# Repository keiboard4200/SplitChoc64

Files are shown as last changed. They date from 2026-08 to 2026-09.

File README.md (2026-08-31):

# SplitChoc64

SplitChoc64 is a 64-key split low-profile keyboard project built around Seeed XIAO nRF52840 and ZMK.

This repository contains firmware/software, PCB design, mechanical/3D-print data, manufacturing outputs, and project documentation.

## Repository layout

```text
SplitChoc64/
├─ hardware/                 # PCB, case, plate, trackball mechanical data and manufacturing files
│  ├─ main-pcb/
│  │  ├─ Ver000/
│  │  └─ Ver001/
│  └─ trackball-addon/
├─ software/                 # ZMK build/config/module source and archived firmware variants
│  ├─ build.yaml
│  ├─ west.yml
│  ├─ zmk-module/            # active Ver001 ZMK module
│  ├─ firmware/
│  │  ├─ joystick/           # legacy Ver000/2765 implementation
│  │  └─ trackball/          # Ver001 PAW3222 documentation
│  └─ tools/
├─ docs/                     # Project documentation
├─ archive/                  # Historical/original import data
├─ DEVELOPMENT/              # Development snapshots retained for traceability
├─ zephyr/module.yml         # Zephyr entry point redirecting to software/zmk-module
├─ .github/                  # GitHub Actions
└─ README.md
```

## Hardware baseline

- **Ver000**: first manufactured SplitChoc64 production hardware baseline (legacy internal name: Ver012).
- **Ver001**: current manufactured hardware/firmware baseline, stored under `hardware/main-pcb/Ver001/`.
- Kailh Choc V2 hot-swap switches.
- Seeed XIAO nRF52840 Plus on both halves.

## Active Ver001 pointing device

Ver001 uses the RIGHT-side PAW3222 trackball through the PCB-mounted 6-pin FFC interface. The active ZMK module under `software/zmk-module/` is configured for this hardware.

The older 2765 analog-joystick implementation is retained only as a legacy reference under `software/firmware/joystick/`; it is not compiled into the active Ver001 firmware.

Detailed Ver001 trackball wiring and firmware notes are in `software/firmware/trackball/README.md`.

## ZMK build

GitHub Actions reads:

- Build matrix: `software/build.yaml`
- West/config path: `software/`
- SplitChoc64 Zephyr/ZMK module: `software/zmk-module/`

`zephyr/module.yml` remains at repository root because ZMK/Zephyr module discovery expects the module entry point there. The implementation is organized under `software/`.

## Firmware identity

- Shield: `splitchoc64_left` / `splitchoc64_right`
- RIGHT: Central / USB-BLE host / PAW3222 trackball
- LEFT: Peripheral
- Bluetooth name: `SplitChoc64`
- ZMK Studio: retained
- `settings_reset` build: retained

## Validation status

GitHub Actions validates LEFT, RIGHT, and `settings_reset` builds. Physical PAW3222 direction, CPI and feel must still be tuned on the assembled Ver001 hardware.

## License

See the license files and upstream component licenses included with each subproject before redistribution or commercial use.

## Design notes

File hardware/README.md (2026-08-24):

# Hardware

This directory contains PCB source data, manufacturing outputs, and hardware-specific documentation.

## Main PCB

`main-pcb/Ver012/` is the frozen production baseline for the manufactured SplitChoc64 PCB.

Do not change:
- PCB outline
- key positions
- left/right interlocking geometry

## Trackball add-on

`trackball-addon/` contains the J4-to-FFC adapter PCB and associated manufacturing/mechanical data for the PAW3222/Torabo variant.

Where practical, keep editable source data and manufacturing outputs together and clearly versioned.

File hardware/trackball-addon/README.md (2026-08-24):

# Trackball add-on hardware

This directory is the canonical location for the SplitChoc64 trackball add-on.

## Version baseline

- Formal repository production version: **Ver000**
- Legacy/internal package label: **Ver003**
- Ver000 preserves the approved Ver003 payload unchanged; only repository-level version designation is changed.
- Next trackball add-on revision: **Ver001**

## Mechanical baseline

- Torabo-tsuki LP 19 mm holder geometry
- 19.05 mm POM ball
- PAW3222 14 mm mouse sensor module
- dedicated R27 trackball adapter
- trackball-enabled RIGHT bottom case

## FFC adapter

The adapter PCB connects RIGHT J4 to a 6-pin 0.5 mm FFC connector.

### J4 mapping

| J4 | Function |
|---|---|
| 1 | 3V3 |
| 2 | GND |
| 3 | SCLK / P0.02 |
| 4 | SDIO / P0.03 |
| 5 | MOTION / P0.28 |
| 6 | CS / P0.04 |
| 7 | SPARE / P0.05 |

### FFC-side mapping

| J2 | Function |
|---|---|
| 1 | GND |
| 2 | SCLK |
| 3 | SDIO |
| 4 | MOTION |
| 5 | CS |
| 6 | 3V3 |

The physical connector orientation and same-side FFC contact direction must be checked during assembly; do not infer conductor order from the U-fold alone.

## Manufacturing baseline

The approved adapter mechanical revision is R27. Reference assemblies are for fit/visualization only and are not themselves manufacturing parts.

Legacy filenames and internal documents may still contain `Ver003`, `R27`, or `R26`; those names are intentionally retained for traceability to the approved manufacturing data.

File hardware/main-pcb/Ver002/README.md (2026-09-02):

# SplitChoc64 Ver002

Clean GitHub source promoted from the user-reviewed XIAO nRF52840 Plus correction.

- `0_COMMON`: shared footprints / 3D assets
- `1_RIGHT`: RIGHT KiCad project + ERC/DRC reports
- `2_LEFT`: LEFT KiCad project + ERC/DRC reports
- `3_PLATE`: accepted TopPlate STEP files
- `4_CASE`: accepted BottomCase / BatteryLid / trackball mechanical STEP files
- Manufacturing exports are intentionally not carried forward from Ver001; regenerate them from Ver002 when needed.

Validation confirmed by the user in KiCad 9.0 before promotion: LEFT/RIGHT ERC 0/0 and DRC 0/0.

Ver002 corrects XIAO nRF52840 Plus pads 28/29, removes unverified pads 30/31, preserves the project-specific front-side solder access pads 32/33, and leaves Ver001 unchanged as historical source.

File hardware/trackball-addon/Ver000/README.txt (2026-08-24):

SplitChoc64 Trackball Add-on Ver003

Purpose:
  Manufacturing package for the SplitChoc64 Ver012 trackball add-on.
  The original Ver012 keyboard PCB geometry is not modified by this package.

Folder layout:
  1_FFC_ADAPTER/   KiCad 9 data for the J4 1.27 mm -> 6P 0.5 mm FFC adapter
  2_3D_PRINT/      3D manufacturing data separated by printable part
    1_TORABO_TRACKBALL_HOLDER/  Torabo-tsuki 19 mm trackball holder
    2_ADAPTER/                  SplitChoc64 external trackball adapter
    3_BOTTOM_CASE/              RIGHT bottom case with trackball interface / FFC pass-through
    4_REFERENCE_ASSEMBLY/       Reference-only assembled placement model; do not manufacture as one part
  3_DOCUMENTS/     Pin map, FFC routing and assembly notes
  VALIDATION_STAGE/ hashes and packaging notes

Important:
  The three manufacturing STEP files under folders 1-3 are each a single valid solid.
  The reference assembly is for placement/fit visualization only.

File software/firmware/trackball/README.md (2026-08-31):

# SplitChoc64 Ver001 trackball firmware

Ver001 uses the PAW3222-based 14 mm mouse-sensor module on the RIGHT / Central half through the PCB-mounted 6-pin FFC connector.

## Ver001 hardware interface

The finalized RIGHT PCB exposes the trackball through J6 (`FH19C-6S-0.5SH`) on the B-side.

PCB J6 net order:

| J6 pin | PCB net | XIAO pin | nRF52840 GPIO |
|---|---|---|---|
| 1 | GND | GND | - |
| 2 | R_EXT_A | D0/A0 | P0.02 |
| 3 | R_EXT_B | D1/A1 | P0.03 |
| 4 | R_EXT_SDA | D4/SDA | P0.04 |
| 5 | R_EXT_SCL | D5/SCL | P0.05 |
| 6 | 3V3 | 3V3 | - |

The sensor-module FFC order is `1=3V3, 2=CS, 3=MOTION, 4=SDIO, 5=SCLK, 6=GND`.
With the same-electrode FFC between the opposing connectors, the order is reversed at the PCB connector. Therefore the firmware assignment is:

| PAW3222 signal | XIAO / GPIO |
|---|---|
| SCLK | D0 / P0.02 |
| SDIO | D1 / P0.03 |
| MOTION | D4 / P0.04 |
| CS | D5 / P0.05 |

The PAW3222 uses 3-wire SPI, so the same SDIO GPIO is assigned to both SPIM MOSI and MISO.

## ZMK integration

The active Ver001 build uses `sekigon-gonnoc/zmk-driver-paw3222` as a West module. RIGHT remains the split Central / USB-BLE host-facing half, and the trackball is local to RIGHT, so split input relay is not required for the normal Ver001 configuration.

The Ver000/legacy 2765 joystick implementation is retained separately under `software/firmware/joystick/` and is not compiled into the active Ver001 build.

## Initial Ver001 behavior

- Trackball: normal pointer movement through PAW3222
- Lay1: explicit mouse buttons and scroll key controls retained
- Lay3: Bluetooth/output management and ZMK Studio unlock retained
- Legacy joystick tuning bindings removed from the active Ver001 keymap

Pointer CPI/rotation and ball-based scrolling should be tuned on the assembled Ver001 hardware after physical bring-up.

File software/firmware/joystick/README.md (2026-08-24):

# Joystick firmware

This directory is a snapshot of the validated SplitChoc64 ZMK firmware for the RIGHT-side 2765 analog joystick configuration.

## Status

- RIGHT = Central / USB-BLE host
- LEFT = Peripheral
- Current production PCB baseline = Ver012
- JOY_X = P0.02 / ADC0
- JOY_Y = P0.03 / ADC1
- Sampling target = 125 Hz
- ZMK Studio retained

During the repository-layout migration, the same firmware is intentionally kept at repository root so the existing GitHub Actions workflow is not broken before path-aware build validation is completed.

Do not modify Ver012 hardware geometry from firmware work.

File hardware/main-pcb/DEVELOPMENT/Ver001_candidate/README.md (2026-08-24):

# SplitChoc64 Ver001 candidate — DEVELOPMENT

**Status: under development / not a formal release.**

This directory is intentionally separated from formal `Ver000` and future formal `Ver001`.
It contains the current DRC-clean PCB candidate while mechanical and connector changes are still pending.

Current PCB baseline:
- LEFT: final mating outline, H4 moved 3.0 mm left, user routing corrections, local silk fix.
- RIGHT: final mating outline, user routing corrections, local silk fix.
- DRC: user-confirmed 0 errors / 0 warnings on 2026-08-24 using the Ver000 project rule set.
- Component placement, nets and schematic intent otherwise inherit Ver000 unless explicitly changed above.
- KiCad project/schematic/library tables and referenced component 3D models are inherited from Ver000.

Mating geometry:
- Main seam key-center pitch accepted at approximately 20.05 mm.
- Case inner wall target: PCB edge +0.2 mm clearance.
- Case wall thickness target: 1.0 mm.

## Next development tasks
1. Change J3/J4 to FFC connectors.
2. Change the battery connector so the battery-side terminal does not need modification.
3. Design the top plate as 3D-printable data.
4. Define/design the bottom plate.

Do not generate manufacturing data from this folder until these tasks are complete and DRC/mechanical checks are repeated.

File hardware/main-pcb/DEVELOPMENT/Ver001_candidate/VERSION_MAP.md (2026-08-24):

# Production Version Map

| Repository version | Legacy/internal label | Meaning |
|---|---|---|
| Ver000 | Ver012 | First manufactured SplitChoc64 production hardware baseline |
| Ver001 | — | Reserved for the first future hardware revision |

The Ver000 design payload is intentionally preserved from the source package originally named `splitchoc64_Ver012.zip`. Legacy names inside KiCad files, validation documents, STEP filenames, and manufacturing outputs are retained for traceability rather than rewritten.

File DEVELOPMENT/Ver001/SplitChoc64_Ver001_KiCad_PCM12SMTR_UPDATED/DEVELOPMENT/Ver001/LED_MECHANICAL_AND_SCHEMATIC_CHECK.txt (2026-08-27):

SplitChoc64 Ver001 LED verification

Mechanical placement
- LED package target: ROHM SMLD12WBN1W1 class, 1.6 x 0.8 x ~0.55 mm.
- LED centers remain at each switch-local (0, -5.15 mm), transformed by switch rotation.
- This position is within the intended Kailh Choc LED-window region used for the V1/V2 hybrid layout.
- No dedicated PCB opening is added.

Silkscreen
- Added visible F.SilkS user text: LED
- Removed the old cathode line at local x=-0.95 mm because it crossed pad 1.
- New cathode line: local x=-1.45 mm, y=-0.45..+0.45 mm, width 0.12 mm.
- Pad 1 local copper/mask x extent: -1.15..-0.35 mm.
- Centerline clearance from pad/mask edge: 0.30 mm; closest silk line edge clearance: ~0.24 mm.

Schematic cross-check
- Repository schematic is older than the uploaded Ver001 PCB state.
- Repository LEFT schematic still contains J3 as 7-pin and old JOY signal naming.
- Uploaded PCB U1 already uses L_EXT_A, L_EXT_B, L_BL_PWM, L_EXT_SDA, L_EXT_SCL etc.
- Therefore an LED-only schematic edit would preserve an existing PCB/schematic mismatch.
- Schematic was intentionally NOT overwritten in this package; a current synchronized schematic source is required before making the full schematic update safely.

No LED routing was added.

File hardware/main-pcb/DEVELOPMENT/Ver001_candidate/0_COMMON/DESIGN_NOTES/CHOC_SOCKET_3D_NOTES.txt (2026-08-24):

SplitChoc64 STAGE279 - Kailh Choc hot-swap socket 3D

Part: CPG135001S30
Applied to: 64 switch footprints
Model: kailh_choc_socket_CPG135001S30_MECH.step

Case-design focus:
- Socket is on the PCB underside.
- Nominal modeled underside depth: 1.85 mm.
- Do not design the case floor exactly tangent to the model.
- Recommended next step is to inspect the assembled PCB in KiCad 3D Viewer and
  then establish the real battery + socket + solder clearance stack.

This is a mechanical clearance model, not an official Kailh STEP.

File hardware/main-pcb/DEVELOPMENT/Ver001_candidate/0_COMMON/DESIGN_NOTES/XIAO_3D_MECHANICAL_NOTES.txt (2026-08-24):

SplitChoc64 STAGE278 - XIAO nRF52840 Plus 3D mechanical model

Purpose:
- Enclosure / case clearance review.
- USB-C connector overhang verification.

Dimensions taken from the existing U1/U2 footprint:
- XIAO module PCB body: approximately 20.950 x 17.800 mm
- USB-C envelope: 6.350 x 7.620 mm
- USB-C protrusion beyond XIAO PCB edge: 1.515 mm

Important:
This STEP is a mechanical proxy. The PCB body and USB-C envelope follow the
existing footprint geometry. Small components are representative shapes.
It is not claimed to be an official Seeed Studio XIAO nRF52840 Plus STEP model.

For case design, the USB-C opening should not be made exactly 1.515 mm deep;
provide assembly/printing tolerance around the connector.

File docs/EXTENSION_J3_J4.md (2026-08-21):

# J3/J4 expansion header (Ver012)

The five signal pins are deliberately **not consumed by RC1**.

| Header pin | Net suffix | XIAO pad | XIAO name | nRF52840 |
|---|---|---:|---|---|
| 1 | 3V3 | 12 | 3V3 | power |
| 2 | GND | 13/33 | GND | ground |
| 3 | JOY_X | 1 | D0 | P0.02 |
| 4 | JOY_Y | 2 | D1 | P0.03 |
| 5 | JOY_SW | 3 | D2 | P0.28 |
| 6 | JOY_SDA | 5 | D4 | P0.04 |
| 7 | JOY_SCL | 6 | D5 | P0.05 |

This leaves all five GPIO signals available for a future analog joystick, I2C device,
or remapped SPI pointing-device interface without changing the manufactured keyboard PCB.

Do not add the pointing driver to RC1 until the base keyboard firmware has been validated.

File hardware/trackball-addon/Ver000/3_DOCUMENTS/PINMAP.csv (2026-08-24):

J4/J1 pin | J4 net | Adapter J2 pin | FFC conductor to sensor pin | Sensor signal
1 | 3V3 | 6 | 1 | 3V3
2 | GND | 1 | 6 | GND
3 | SCLK | 2 | 5 | SCLK
4 | SDIO | 3 | 4 | SDIO
5 | MOTION | 4 | 3 | MOTION
6 | CS | 5 | 2 | CS
7 | SPARE | NC | NC | NC

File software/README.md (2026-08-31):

# Software

This directory contains the software and firmware side of SplitChoc64.

## Layout

- `build.yaml` — ZMK build matrix used by GitHub Actions.
- `west.yml` — West manifest for fetching ZMK and dependencies.
- `zmk-module/` — SplitChoc64 Zephyr/ZMK module source, board/shield definitions, devicetree bindings and C sources.
- `firmware/joystick/` — preserved joystick firmware variant.
- `firmware/trackball/` — trackball firmware variant.
- `tools/` — software-side helper and validation tools.

## Build integration

The repository keeps only `zephyr/module.yml` at the repository root as the Zephyr module entry point. It points into `software/zmk-module/`.

GitHub Actions uses `software/build.yaml` as the build matrix and `software/` as the ZMK config path. This keeps the repository root readable without changing the hardware tree.

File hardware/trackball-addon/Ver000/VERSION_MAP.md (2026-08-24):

# Trackball Add-on Version Map

| Repository version | Legacy/internal label | Meaning |
|---|---|---|
| Ver000 | Ver003 | First approved/manufactured SplitChoc64 trackball add-on baseline |
| Ver001 | — | Reserved for the first future trackball add-on revision |

The Ver000 payload is intentionally preserved from the data previously managed as Trackball Add-on Ver003. Internal R27/R26 and Ver003 names are retained where present for traceability rather than rewritten.

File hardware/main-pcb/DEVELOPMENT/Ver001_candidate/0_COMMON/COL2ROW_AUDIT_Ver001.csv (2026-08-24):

Side | key | switch | diode | ROW | SW_to_K | A_to_COL
LEFT | 1 | SWL1 | DL1 | L_ROW0 | L_K1_D | L_COL0
LEFT | 2 | SWL2 | DL2 | L_ROW0 | L_K2_D | L_COL1
LEFT | 3 | SWL3 | DL3 | L_ROW0 | L_K3_D | L_COL2
LEFT | 4 | SWL4 | DL4 | L_ROW0 | L_K4_D | L_COL3
LEFT | 5 | SWL5 | DL5 | L_ROW0 | L_K5_D | L_COL4
LEFT | 6 | SWL6 | DL6 | L_ROW0 | L_K6_D | L_COL5
LEFT | 7 | SWL7 | DL7 | L_ROW1 | L_K7_D | L_COL0
LEFT | 8 | SWL8 | DL8 | L_ROW1 | L_K8_D | L_COL1
LEFT | 9 | SWL9 | DL9 | L_ROW1 | L_K9_D | L_COL2
LEFT | 10 | SWL10 | DL10 | L_ROW1 | L_K10_D | L_COL3
LEFT | 11 | SWL11 | DL11 | L_ROW1 | L_K11_D | L_COL4
LEFT | 12 | SWL12 | DL12 | L_ROW1 | L_K12_D | L_COL5
LEFT | 13 | SWL13 | DL13 | L_ROW2 | L_K13_D | L_COL0
LEFT | 14 | SWL14 | DL14 | L_ROW2 | L_K14_D | L_COL1
LEFT | 15 | SWL15 | DL15 | L_ROW2 | L_K15_D | L_COL2
LEFT | 16 | SWL16 | DL16 | L_ROW2 | L_K16_D | L_COL3
LEFT | 17 | SWL17 | DL17 | L_ROW2 | L_K17_D | L_COL4
LEFT | 18 | SWL18 | DL18 | L_ROW2 | L_K18_D | L_COL5
LEFT | 19 | SWL19 | DL19 | L_ROW3 | L_K19_D | L_COL0
LEFT | 20 | SWL20 | DL20 | L_ROW3 | L_K20_D | L_COL1
LEFT | 21 | SWL21 | DL21 | L_ROW3 | L_K21_D | L_COL2
LEFT | 22 | SWL22 | DL22 | L_ROW3 | L_K22_D | L_COL3
LEFT | 23 | SWL23 | DL23 | L_ROW3 | L_K23_D | L_COL4
LEFT | 24 | SWL24 | DL24 | L_ROW3 | L_K24_D | L_COL5
LEFT | 25 | SWL25 | DL25 | L_ROW4 | L_K25_D | L_COL0
LEFT | 26 | SWL26 | DL26 | L_ROW4 | L_K26_D | L_COL1
LEFT | 27 | SWL27 | DL27 | L_ROW4 | L_K27_D | L_COL2
LEFT | 28 | SWL28 | DL28 | L_ROW4 | L_K28_D | L_COL3
LEFT | 29 | SWL29 | DL29 | L_ROW4 | L_K29_D | L_COL4
RIGHT | 1 | SWR1 | DR1 | R_ROW0 | R_K1_D | R_COL0
RIGHT | 2 | SWR2 | DR2 | R_ROW0 | R_K2_D | R_COL1
RIGHT | 3 | SWR3 | DR3 | R_ROW0 | R_K3_D | R_COL2
RIGHT | 4 | SWR4 | DR4 | R_ROW0 | R_K4_D | R_COL3
RIGHT | 5 | SWR5 | DR5 | R_ROW0 | R_K5_D | R_COL4
RIGHT | 6 | SWR6 | DR6 | R_ROW0 | R_K6_D | R_COL5
RIGHT | 7 | SWR7 | DR7 | R_ROW0 | R_K7_D | R_COL6
RIGHT | 8 | SWR8 | DR8 | R_ROW0 | R_K8_D | R_COL7
RIGHT | 9 | SWR9 | DR9 | R_ROW1 | R_K9_D | R_COL0
RIGHT | 10 | SWR10 | DR10 | R_ROW1 | R_K10_D | R_COL1
RIGHT | 11 | SWR11 | DR11 | R_ROW1 | R_K11_D | R_COL2
RIGHT | 12 | SWR12 | DR12 | R_ROW1 | R_K12_D | R_COL3
RIGHT | 13 | SWR13 | DR13 | R_ROW1 | R_K13_D | R_COL4
RIGHT | 14 | SWR14 | DR14 | R_ROW1 | R_K14_D | R_COL5
RIGHT | 15 | SWR15 | DR15 | R_ROW1 | R_K15_D | R_COL6
RIGHT | 16 | SWR16 | DR16 | R_ROW1 | R_K16_D | R_COL7
RIGHT | 17 | SWR17 | DR17 | R_ROW2 | R_K17_D | R_COL0
RIGHT | 18 | SWR18 | DR18 | R_ROW2 | R_K18_D | R_COL1
RIGHT | 19 | SWR19 | DR19 | R_ROW2 | R_K19_D | R_COL2
RIGHT | 20 | SWR20 | DR20 | R_ROW2 | R_K20_D | R_COL3
RIGHT | 21 | SWR21 | DR21 | R_ROW2 | R_K21_D | R_COL4
RIGHT | 22 | SWR22 | DR22 | R_ROW2 | R_K22_D | R_COL5
RIGHT | 23 | SWR23 | DR23 | R_ROW2 | R_K23_D | R_COL6
RIGHT | 24 | SWR24 | DR24 | R_ROW3 | R_K24_D | R_COL0
RIGHT | 25 | SWR25 | DR25 | R_ROW3 | R_K25_D | R_COL1
RIGHT | 26 | SWR26 | DR26 | R_ROW3 | R_K26_D | R_COL2
RIGHT | 27 | SWR27 | DR27 | R_ROW3 | R_K27_D | R_COL3
RIGHT | 28 | SWR28 | DR28 | R_ROW3 | R_K28_D | R_COL4
RIGHT | 29 | SWR29 | DR29 | R_ROW3 | R_K29_D | R_COL5
RIGHT | 30 | SWR30 | DR30 | R_ROW4 | R_K30_D | R_COL0
RIGHT | 31 | SWR31 | DR31 | R_ROW4 | R_K31_D | R_COL1
RIGHT | 32 | SWR32 | DR32 | R_ROW4 | R_K32_D | R_COL2
RIGHT | 33 | SWR33 | DR33 | R_ROW4 | R_K33_D | R_COL3
RIGHT | 34 | SWR34 | DR34 | R_ROW4 | R_K34_D | R_COL4
RIGHT | 35 | SWR35 | DR35 | R_ROW4 | R_K35_D | R_COL5

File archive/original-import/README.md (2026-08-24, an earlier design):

# Original import archive

This directory preserves the original user-uploaded manufacturing source archive before repository relabeling.

- Original filename: `splitchoc64_Ver012.zip`
- Legacy/internal hardware label: `Ver012`
- Formal repository production version: **Ver000**

The archive is retained unchanged for traceability. The canonical extracted production data is under `hardware/main-pcb/Ver000/`.

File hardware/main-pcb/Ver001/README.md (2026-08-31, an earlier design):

# SplitChoc64 Ver001

Clean GitHub upload package, organized to follow Ver000.

- `0_COMMON`: shared footprints / 3D assets
- `1_RIGHT`: RIGHT KiCad project + latest ERC/DRC reports
- `2_LEFT`: LEFT KiCad project + latest ERC/DRC reports
- `3_PLATE`: accepted TopPlate STEP files
- `4_CASE`: accepted BottomCase / BatteryLid / trackball mechanical STEP files
- `5_MANIFUCTUR`: manufacturing exports (LEFT/RIGHT fabrication ZIPs and expanded Gerber/drill outputs)

Validation reports included with KiCad projects:
- LEFT: ERC 0 errors / 0 warnings; DRC 0 violations / 0 unconnected / 0 footprint errors
- RIGHT: ERC 0 errors / 0 warnings; DRC 0 violations / 0 unconnected / 0 footprint errors

`SHA256SUMS.txt` records SHA-256 values that were explicitly verified for the release-critical PCB and mechanical source artifacts. It is not a claim that the files under `5_MANIFUCTUR` were regenerated from the current KiCad PCB in this repository. A byte-for-byte regenerated Gerber/drill comparison requires a matching KiCad 9 `kicad-cli` environment.

The current accepted mechanical revisions in `4_CASE` include Ver001.006 LEFT BottomCase, Ver001.005 RIGHT BottomCase, Ver001.006 LEFT/RIGHT BatteryLids, Ver001.004 LEFT/RIGHT TopPlates, and the LEFT/RIGHT trackball adapters. The trackball-holder STEP is retained as a manufacturing/mechanical dependency but is not listed in `SHA256SUMS.txt` unless its SHA-256 has been explicitly revalidated.

This package intentionally omits intermediate revision files, temporary validation notes, screenshots, old mechanical versions, and development history artifacts.

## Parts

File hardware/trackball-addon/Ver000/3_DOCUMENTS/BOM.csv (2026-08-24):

Ref | Item | Specification | Qty | Notes
J1 | Low-profile pin header/socket | 1x7 1.27mm pitch | 1 | Mates with SplitChoc64 Ver012 J4
J2 | FFC/FPC connector | Hirose FH19C-6S-0.5SH(10) or footprint-compatible | 1 | 6P 0.5mm; B-side mount
FFC | Flat flexible cable | 6P 0.5mm same-contact-side | 1 | U-fold 180 degrees; no twist
SENSOR | Mouse sensor module | 14mm PAW3222 module | 1 | Purchased module; not fabricated in this package
BALL | Trackball | 19.05mm nominal | 1 | Torabo-tsuki LP 19mm configuration

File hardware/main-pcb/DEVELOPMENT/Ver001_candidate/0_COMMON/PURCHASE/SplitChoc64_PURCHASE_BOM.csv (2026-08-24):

Category | Part | MPN | Left | Right | Total | Recommended purchase qty | Recommended source | Notes
MCU | Seeed Studio XIAO nRF52840 Plus | 102010672 | 1 | 1 | 2 | 3 | Seeed Studio Japan | Exact Plus version required; one spare recommended.
Keyboard diode | 1N4148WS SOD-323 | JSCJ 1N4148WS / LCSC C2128 | 29 | 35 | 64 | 70 | LCSC | SOD-323. Pin 1 = cathode (K). Align the diode body cathode band with the PCB K/bar mark.
Status LED | Blue LED 0603 | KT-0603B / C2288 | 1 | 1 | 2 | 50 | LCSC | LCSC minimum 50; polarity critical.
LED resistor | 100Ω 1% 0603 | 0603WAF1000T5E / C22775 | 1 | 1 | 2 | 100 | LCSC | Any equivalent 100Ω 0603 1% is acceptable.
Power switch | SPDT slide switch | C&K PCM12SMTR | 1 | 1 | 2 | 4 | DigiKey | Obsolete; buy spares. Exact mechanical footprint matters.
Battery PCB connector | JST SH 2-pin SMT | BM02B-SRSS-TB(LF)(SN) / C160388 | 1 | 1 | 2 | 5 | LCSC | 1.0mm pitch; fine hand-soldering.
Joystick header | 1.27mm 1x7 male header | generic | 1 | 1 | 2 | 4 | DigiKey/Mouser/Akizuki | Confirm pin diameter fits 0.70mm drill.
Joystick | 2-axis analog joystick | JT8P-3.2T-B10K-1-16Y | 1 | 1 | 2 | 3 | Akizuki | Requires wiring/adapter to J3/J4.
Hotswap socket | Kailh Choc hotswap socket | CPG135001S30 | 29 | 35 | 64 | 70 | Yusha Kobo | 10-pack product; buy 7 packs.
Key switch | Kailh Choc V2 | e.g. CPG135301D01 Red | 29 | 35 | 64 | 70 | Yusha Kobo / Marutsu Eleshop | Two 35-packs gives 70.
Battery mating lead | JST SH 2-pin housing/contact | SHR-02V-S(-B) + SSH-003T-P0.2-H | 1 | 1 | 2 | 3 | DigiKey/Mouser | Pre-crimped lead recommended.
Battery | LiPo ~502535 3.7V ~400mAh | DTP502535 or equivalent | 1 | 1 | 2 | 2 | Reputable battery seller | Check polarity, protection circuit and actual thickness.

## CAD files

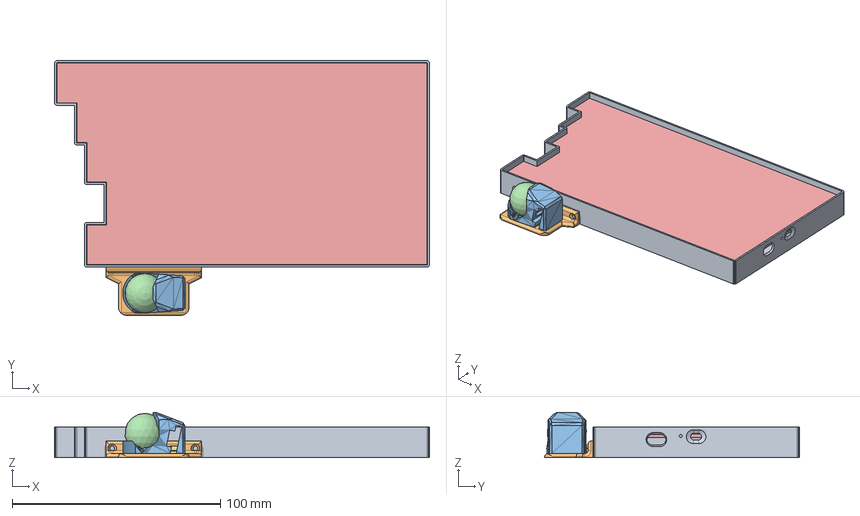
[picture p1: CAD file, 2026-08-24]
hardware/trackball-addon/Ver000/2_3D_PRINT/SplitChoc64_Trackball_Reference_Assembly_R26.step
180.1 x 122.3 x 21.8 mm
RIGHT_BOTTOM_CASE_R24
FINAL_ADAPTER_R24
TORABO19_CASE
BALL_19_005
RIGHT_PCB_REFERENCE
J4_TO_FFC_ADAPTER_PCB_11x8x0.8
J4_1x7_1.27_MATING_CONNECTOR_ENVELOPE
FFC_6P_0.5_CONNECTOR_OPENING_AWAY_FROM_HOLE
FFC_OUTWARD_SEGMENT
FFC_180_FOLDBACK_REGION
FFC_RETURN_SEGMENT
FFC_INTO_EXISTING_SIDEWALL_HOLE

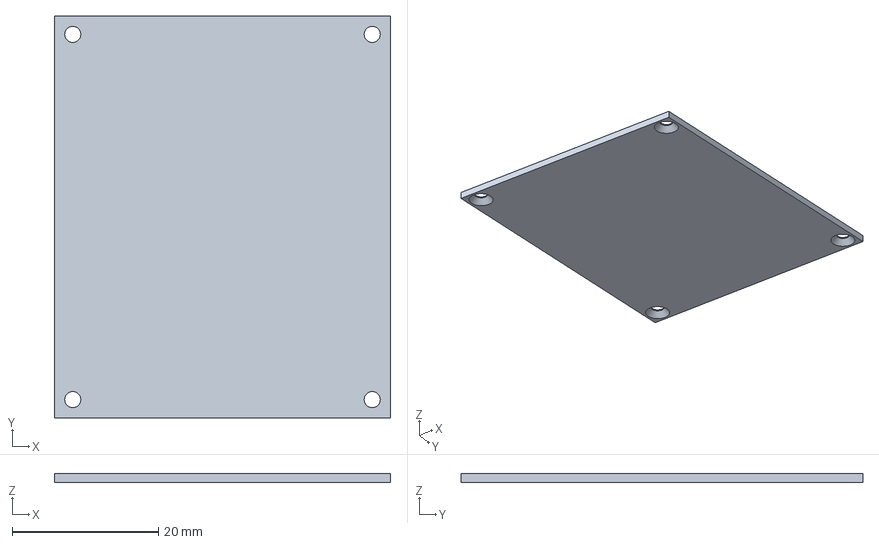
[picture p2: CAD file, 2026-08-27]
DEVELOPMENT/Ver001/SplitChoc64_Ver001_KiCad_PCM12SMTR_UPDATED/DEVELOPMENT/Ver001/MECHANICAL/BottomCase_V1/SplitChoc64_LEFT_BatteryLid_V1.step
46.0 x 55.0 x 1.20 mm

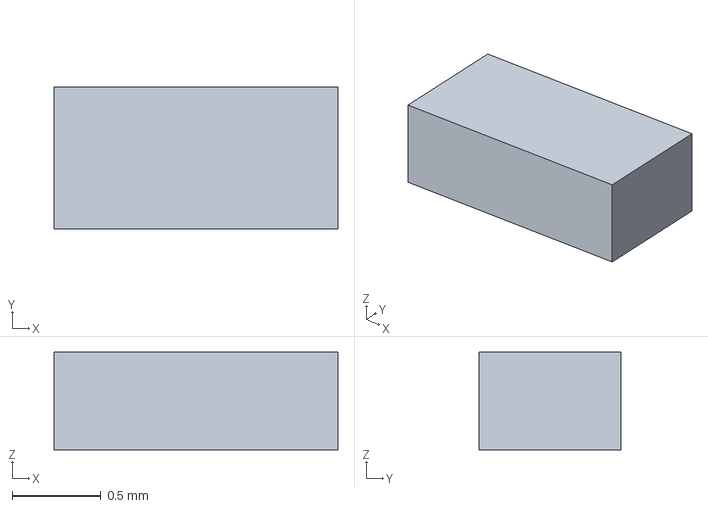
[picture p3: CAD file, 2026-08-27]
hardware/main-pcb/Ver002/1_RIGHT/3dmodels/LED_0603_1608_TOP_PROXY.step
1.60 x 0.8 x 0.55 mm

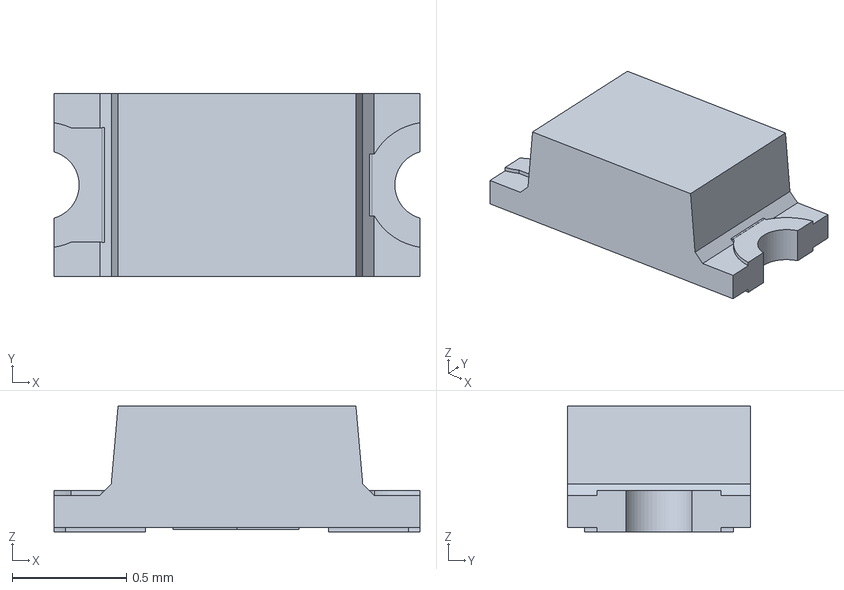
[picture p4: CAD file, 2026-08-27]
hardware/main-pcb/Ver002/2_LEFT/3dmodels/ROHM_SMLD12WBN1W1_KICAD_ALIGNED.step
1.60 x 0.8 x 0.55 mm

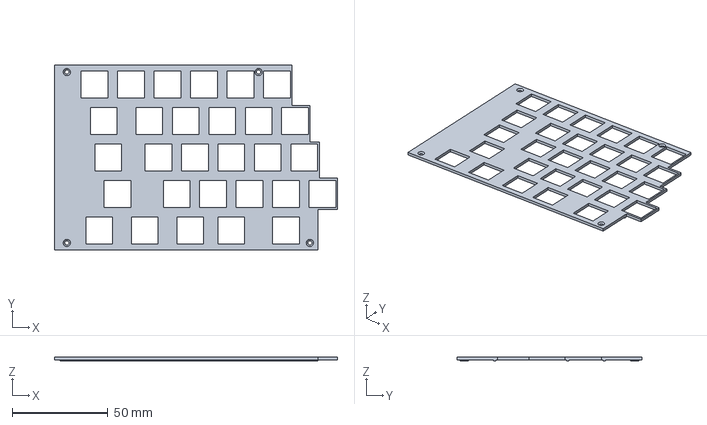
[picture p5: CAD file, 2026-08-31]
hardware/main-pcb/Ver002/3_PLATE/SplitChoc64_LEFT_TopPlate.step
147.9 x 96.8 x 2.10 mm

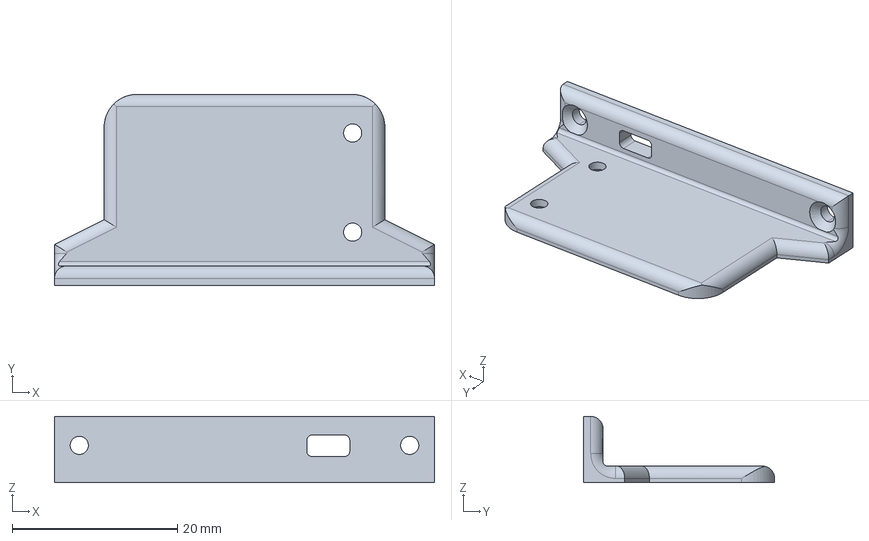
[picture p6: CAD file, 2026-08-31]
hardware/main-pcb/Ver002/4_CASE/SplitChoc64_LEFT_Trackball_Adapter.step
46.0 x 23.2 x 8.00 mm

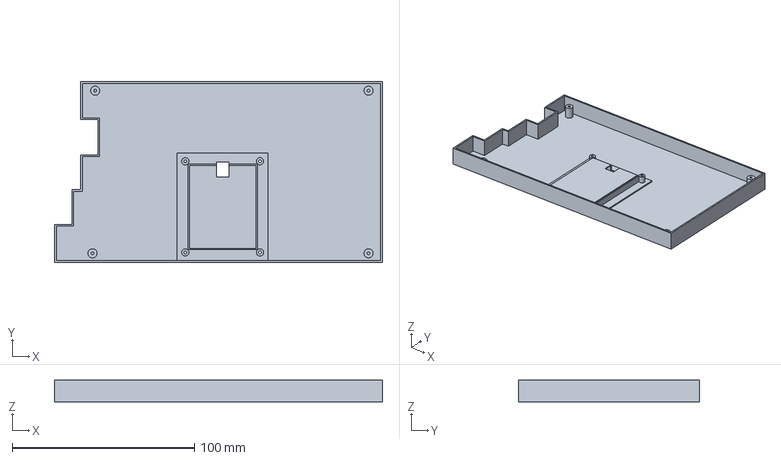
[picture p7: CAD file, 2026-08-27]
DEVELOPMENT/Ver001/SplitChoc64_Ver001_KiCad_PCM12SMTR_UPDATED/DEVELOPMENT/Ver001/MECHANICAL/BottomCase_V1/SplitChoc64_RIGHT_BottomCase_V1.step
180.0 x 99.2 x 11.9 mm

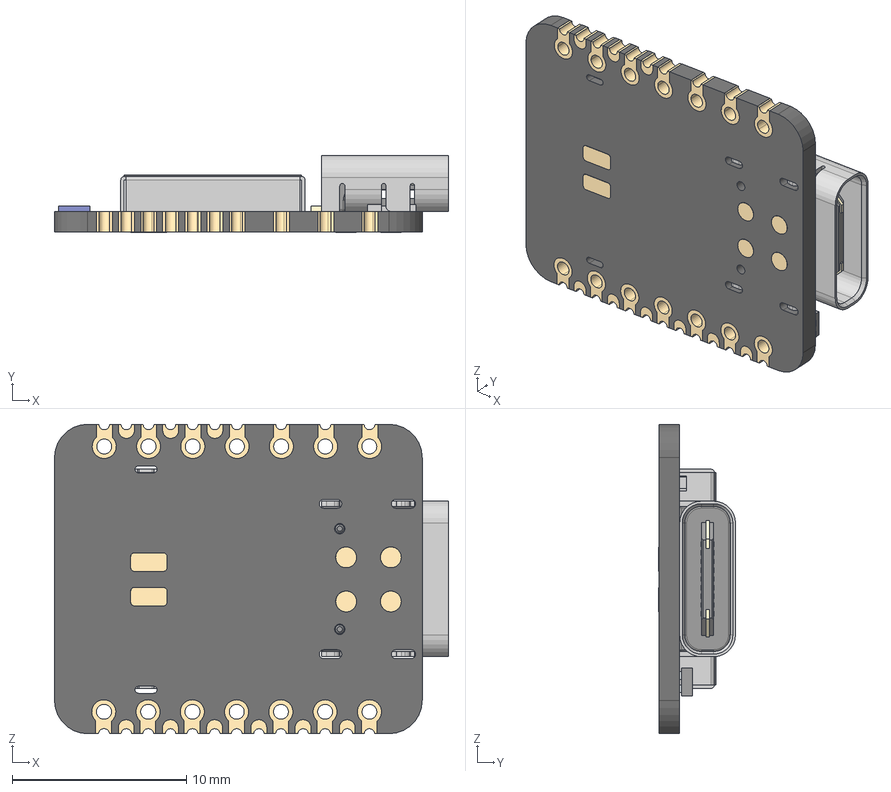
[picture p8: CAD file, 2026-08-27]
hardware/main-pcb/Ver002/1_RIGHT/3dmodels/xiao-nrf52840-plus-v2.step
22.6 x 4.42 x 17.8 mm
BOSS-EXTRUDE14_8_
BOSS-EXTRUDE7_4_
BOSS-EXTRUDE7_3_
BOSS-EXTRUDE14_4_
BOSS-EXTRUDE14_2_
BOSS-EXTRUDE14_11_
BOSS-EXTRUDE7_7_
BOSS-EXTRUDE14_9_
BOSS-EXTRUDE14_3_
BOSS-EXTRUDE14_7_
MIRROR2
BOSS-EXTRUDE14_5_
BOSS-EXTRUDE14_12_
BOSS-EXTRUDE7_8_
BOSS-EXTRUDE7_1_
BOSS-EXTRUDE14_10_
BOSS-EXTRUDE7_9_
BOSS-EXTRUDE14_6_
BOSS-EXTRUDE14_1_
BOSS-EXTRUDE7_6_
BOSS-EXTRUDE7_2_
CUT-EXTRUDE5
BOSS-EXTRUDE7_5_
Shield
Pins

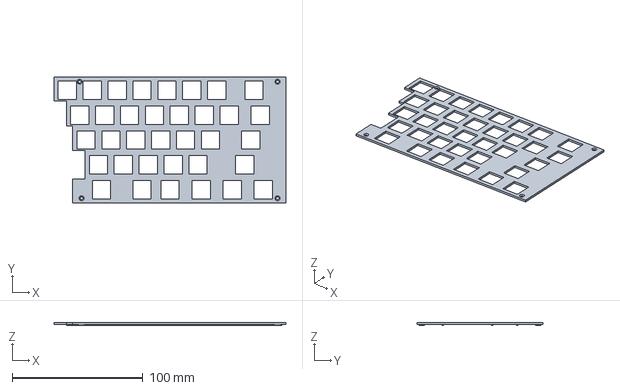
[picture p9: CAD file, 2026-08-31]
hardware/main-pcb/Ver002/3_PLATE/SplitChoc64_RIGHT_TopPlate.step
177.6 x 96.8 x 2.10 mm

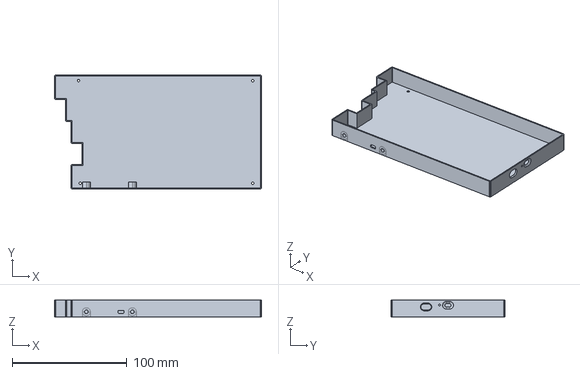
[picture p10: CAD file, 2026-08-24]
hardware/trackball-addon/Ver000/2_3D_PRINT/SplitChoc64_RIGHT_BottomCase_Trackball.step
180.1 x 99.2 x 14.7 mm

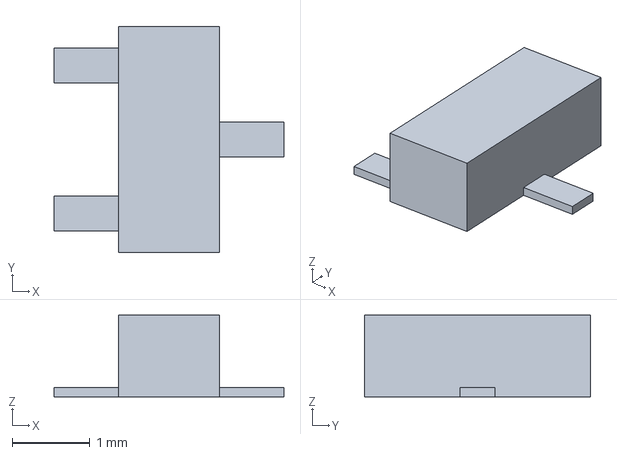
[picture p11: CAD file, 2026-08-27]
hardware/main-pcb/Ver002/1_RIGHT/3dmodels/2N7002_SOT23_KICAD_ALIGNED.step
2.95 x 2.90 x 1.05 mm

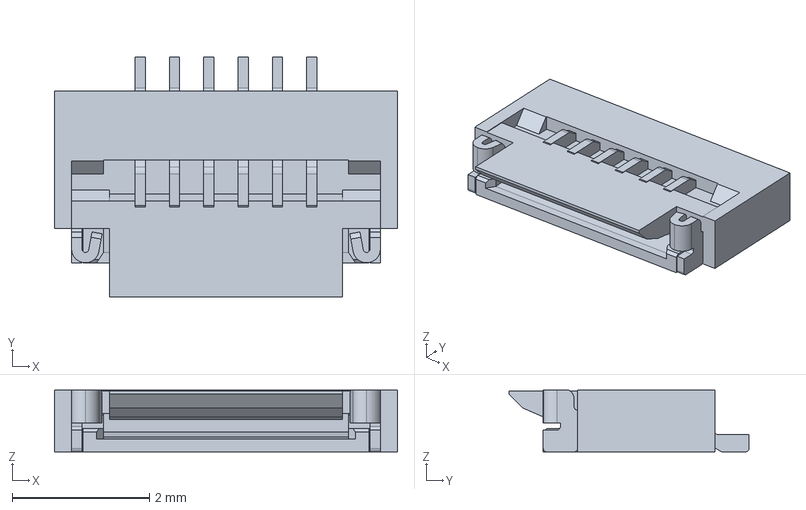
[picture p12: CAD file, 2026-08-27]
hardware/main-pcb/Ver002/2_LEFT/3dmodels/Hirose_FH19C-6S-0.5SH10_KICAD_ALIGNED.step
5.00 x 3.50 x 0.9 mm

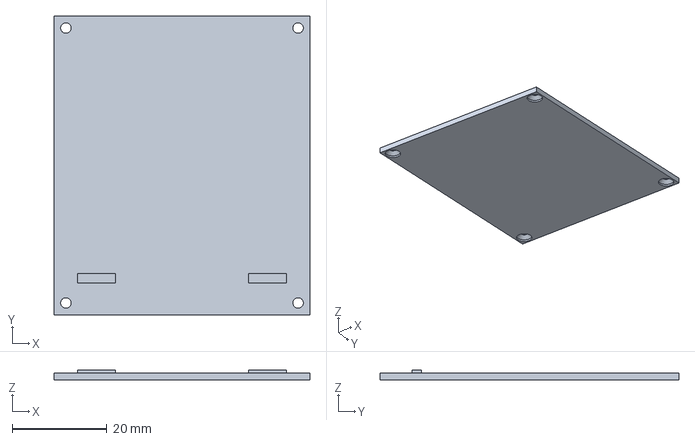
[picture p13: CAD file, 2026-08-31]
hardware/main-pcb/Ver002/4_CASE/SplitChoc64_VER001.006_RIGHT_BatteryLid.step
54.0 x 63.0 x 2.10 mm

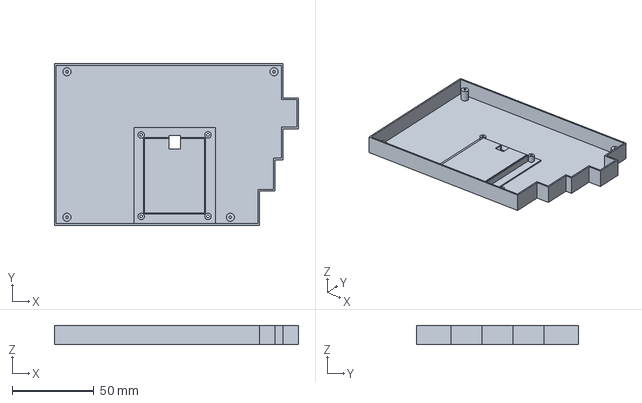
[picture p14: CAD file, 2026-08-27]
DEVELOPMENT/Ver001/SplitChoc64_Ver001_KiCad_PCM12SMTR_UPDATED/DEVELOPMENT/Ver001/MECHANICAL/BottomCase_V1/SplitChoc64_LEFT_BottomCase_V1.step
149.7 x 99.2 x 11.9 mm

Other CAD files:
hardware/main-pcb/Ver002/2_LEFT/3dmodels/LED_0603_1608_TOP_PROXY.step
DEVELOPMENT/Ver001/SplitChoc64_Ver001_KiCad_PCM12SMTR_UPDATED/DEVELOPMENT/Ver001/MECHANICAL/BottomCase_V1/SplitChoc64_RIGHT_BatteryLid_V1.step
hardware/main-pcb/Ver002/1_RIGHT/3dmodels/JST_S2B-PH-SM4-TB_KICAD_ALIGNED.step
DEVELOPMENT/Ver001/SplitChoc64_Ver001_KiCad_PCM12SMTR_UPDATED/DEVELOPMENT/Ver001/MECHANICAL/BottomCase_V1/SplitChoc64_LEFT_BatteryLid_V1.stl
DEVELOPMENT/Ver001/SplitChoc64_Ver001_KiCad_PCM12SMTR_UPDATED/DEVELOPMENT/Ver001/MECHANICAL/BottomCase_V1/SplitChoc64_LEFT_BottomCase_V1.stl
DEVELOPMENT/Ver001/SplitChoc64_Ver001_KiCad_PCM12SMTR_UPDATED/DEVELOPMENT/Ver001/MECHANICAL/BottomCase_V1/SplitChoc64_RIGHT_BatteryLid_V1.stl
DEVELOPMENT/Ver001/SplitChoc64_Ver001_KiCad_PCM12SMTR_UPDATED/DEVELOPMENT/Ver001/MECHANICAL/BottomCase_V1/SplitChoc64_RIGHT_BottomCase_V1.stl
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

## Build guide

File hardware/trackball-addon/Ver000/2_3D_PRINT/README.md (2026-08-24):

# Trackball Add-on Ver003 — 3D assets

The manufacturing package contains these STEP assets:

| Role | File | SHA-256 |
|---|---|---|
| Torabo-tsuki 19 mm holder | `1_TORABO_TRACKBALL_HOLDER/ToraboTsuki_Trackball_Holder_19mm.step` | `7717395efcfe289285835eb16c14c3fb0391c115903c83dc3d8a7b22ab0351f0` |
| SplitChoc64 trackball adapter | `2_ADAPTER/SplitChoc64_Trackball_Adapter.step` | `a29724234e68b600f6e96f09fd6a59213defe4a1de254774ebe799ba476616b3` |
| RIGHT bottom case | `3_BOTTOM_CASE/SplitChoc64_RIGHT_BottomCase_Trackball.step` | `a944e31e2f75782416efe2137fbc5e2f5e7dd0b45cc209864cb6c01c5debe6c8` |
| Reference assembly only | `4_REFERENCE_ASSEMBLY/SplitChoc64_Trackball_Reference_Assembly_R26.step` | `32b3b926071d22d73088b5ba36c1fba255c9a211daec2f892ff4ab1aff8d536f` |

The first three files are manufacturing components. The R26 assembly is reference-only and must not be manufactured as one part.

The source package is `SplitChoc64_Trackball_Addon_Ver003.zip`. The STEP binaries are intentionally tracked separately from the text/KiCad import in this migration step because the connected GitHub writer used for this migration only accepts text or inline blob content and is not suitable for multi-megabyte CAD binaries. The hashes above are authoritative for later binary upload verification.

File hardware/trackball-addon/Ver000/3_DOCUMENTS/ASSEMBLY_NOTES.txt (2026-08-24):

SplitChoc64 Trackball Add-on assembly notes

Signal path:
SplitChoc64 RIGHT J4 -> J1 on adapter PCB -> J2 (B-side) -> 6P 0.5 mm FFC -> PAW3222 14 mm sensor module.

Adapter J2 pin map:
1 GND
2 SCLK
3 SDIO
4 MOTION
5 CS
6 3V3

Sensor module connector pin map:
1 3V3
2 CS
3 MOTION
4 SDIO
5 SCLK
6 GND

With the intended connector facing arrangement and same-contact-side FFC, the physical conductor mapping is adapter 1..6 -> sensor 6..1.
The FFC is U-folded for routing; it is not twisted.

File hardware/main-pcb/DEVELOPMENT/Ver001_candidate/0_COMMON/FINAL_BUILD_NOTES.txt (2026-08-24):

SplitChoc64 Ver000 FINAL

ASSEMBLY
- JLCPCB is used for bare-PCB fabrication only.
- PCBA quantity: 0 components.
- All electronic components are hand-soldered.
- No JLCPCB PCBA BOM/CPL is included.
- Purchase list: 0_COMMON/PURCHASE/SplitChoc64_PURCHASE_BOM.csv

3D
- U1/U2 and all SWL/SWR footprints are now classified as SMD and are no longer excluded from position files.
- XIAO / Choc socket / Choc switch STEP files are copied into each side's local 3dmodels folder.
- This is intended to make them visible in the whole-board KiCad 3D Viewer without relying on P/V special filters.
- No copper, pad, routing, footprint coordinate or Edge.Cuts geometry was changed.

HAND-SOLDERING RISKS
1. JST SH BM02B-SRSS-TB: 1.0mm-pitch SMD; use flux, magnification and a fine tip/hot air.
2. 0603 LED/resistor: small; LED polarity must be checked.
3. 64x 1N4148W: cathode orientation must be checked before soldering.
4. XIAO Plus BAT_SW/GND bottom pads: use the designed plated access slots; solder method needs care.
5. PCM12SMTR: orientation-sensitive and obsolete; buy spare units because the footprint is exact.
6. Choc hot-swap sockets: plastic can deform from excessive iron dwell time.
7. Battery/JST polarity: verify with a multimeter before connecting a LiPo.
8. Joystick is not a direct PCB footprint here; J3/J4 are 1.27mm 1x7 headers, so wiring/adapter is needed.

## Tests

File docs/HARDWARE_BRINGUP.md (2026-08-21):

# Hardware bring-up sequence

1. Flash `settings_reset` once to both XIAO modules if they have existing ZMK bonds/settings.
2. Flash `splitchoc64_left` to LEFT and connect LEFT by USB.
3. Verify LEFT's 29 switches.
4. Flash `splitchoc64_right` to RIGHT.
5. Verify BLE split and all 64 switches.
6. Verify USB and BLE host operation.
7. Only after the base keyboard is proven, add J3/J4 pointing-device firmware.

Do not troubleshoot the future pointing-device driver at the same time as the first matrix/split bring-up.

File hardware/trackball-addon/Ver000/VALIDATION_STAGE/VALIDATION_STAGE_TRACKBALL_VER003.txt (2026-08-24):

SplitChoc64 Trackball Add-on Ver003 validation

3D manufacturing data separated into three standalone STEP files:
- Torabo-tsuki 19 mm holder: 1 solid, valid
- SplitChoc64 trackball adapter: 1 solid, valid
- SplitChoc64 RIGHT bottom case: 1 solid, valid

Adapter source: final R27 (M2 countersunk mounting holes).
Bottom-case source: final R27 case, including the accepted sidewall FFC pass-through.
Torabo holder source: user-provided Fusion-converted Torabo 19 mm STEP.
R26 is retained only as a reference assembly.

Historical DRC reports are intentionally not included.

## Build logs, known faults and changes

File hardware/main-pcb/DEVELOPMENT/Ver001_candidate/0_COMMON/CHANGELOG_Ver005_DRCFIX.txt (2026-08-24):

SplitChoc64 Ver005 — DRC-fix reissue

Reviewed supplied Ver004 DRC reports:
RIGHT: 71 violations; {'silk_over_copper': 36, 'silk_overlap': 35}; unconnected=0; footprint errors=0
LEFT:  59 violations; {'silk_over_copper': 30, 'silk_overlap': 29}; unconnected=0; footprint errors=0

Corrections:
- Kept the user-requested Ver005 logo positions:
  LEFT  (60, 89) mm
  RIGHT (280, 89) mm
- Kept the Choc socket as a filled B.SilkS top-view projection, but removed fill over
  the switch footprint's B.Mask / exposed pad and hole regions with 0.25 mm clearance.
  This addresses the socket silk_over_copper warnings instead of merely suppressing them.
- Moved each keyboard diode 'K' text from local x=-2.55 to x=-3.20 so it no longer
  overlaps its own cathode bar, addressing the silk_overlap warnings.
- No copper, pad, track, net, component coordinate, mounting-hole or Edge.Cuts changes.
- Schematics unchanged.

A fresh KiCad DRC must be run by the user on this reissued Ver005 to verify zero warnings.

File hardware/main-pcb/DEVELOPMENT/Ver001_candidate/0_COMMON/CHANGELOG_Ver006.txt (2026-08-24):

SplitChoc64 Ver006

- LEFT logo moved 5 mm left and 3 mm down: (60,89) -> (55,92).
- Added project-local 3D models to DLED1/DLED2 and RLED1/RLED2.
- Added project-local BM02B-SRSS-TB mechanical proxy to J1/J2.
- DLED/RLED/J1/J2 are explicitly SMD so board-wide 3D Viewer visibility is less filter-dependent.

Ver005 DRC handling:
- RIGHT: 4 silk_edge_clearance warnings at DR1/DR9/DR17/DR24 K labels.
  These K labels were moved inward.
- LEFT: 1 silk_over_copper warning at the SplitChoc64 logo.
  The requested logo move changes that location.
- Both reports: 0 unconnected pads, 0 footprint errors.

3D accuracy:
- LED and resistor are generic 0603 mechanical visualization proxies.
- Battery connector is a mechanical proxy based on the BM02B-SRSS-TB footprint envelope.
  It is not claimed to be a manufacturer-exact cosmetic STEP.

No copper, pads, tracks, nets, component locations, mounting holes or Edge.Cuts changed.
Fresh Ver006 DRC has not been run here.

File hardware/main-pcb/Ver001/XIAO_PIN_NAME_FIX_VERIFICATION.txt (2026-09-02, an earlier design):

SplitChoc64 Ver001 — XIAO nRF52840 Plus pin-name correction review package
==========================================================================

Purpose
-------
Correct schematic/library pin labels for the Seeed Studio XIAO nRF52840 Plus
without changing PCB copper, pad geometry, placement, routing, or 3D models.

Corrected pin names
-------------------
Pad 24: AUX24 -> SWDIO
Pad 25: AUX25 -> SWDCLK
Pad 26: RESET -> EN
Pad 27: GND (unchanged)
Pad 28: AUX28 -> VBAT
Pad 29: AUX29 -> GND

Files intentionally edited
--------------------------
1_RIGHT/SplitChoc64.kicad_sym
1_RIGHT/SC64.kicad_sym
1_RIGHT/SplitChoc64_RIGHT.kicad_sch
2_LEFT/SplitChoc64.kicad_sym
2_LEFT/SC64.kicad_sym
2_LEFT/SplitChoc64_LEFT.kicad_sch

Intentionally NOT changed
-------------------------
- LEFT/RIGHT .kicad_pcb files
- U1/U2 footprint geometry and all pad coordinates/sizes
- pads 30..33
- PCB routing and net assignments
- all STEP/3D model files
- case/top plate/battery lid/trackball geometry
- ERC/DRC rule settings

Baseline checks
---------------
Canonical GitHub hardware/main-pcb/Ver001 PCB blob SHA values checked before packaging:
LEFT  2_LEFT/SplitChoc64_LEFT.kicad_pcb  f4d9ea4f736a971030b46df9c57ce9df1f895ebf
RIGHT 1_RIGHT/SplitChoc64_RIGHT.kicad_pcb dea28b0c6e13e364c5b489c4f8c7c8187acd633a

The package PCB files retain those exact Git blob SHA values.
The XIAO STEP model remains unchanged.

Validation limitation
---------------------
No local KiCad CLI is available in this chat runtime, so ERC/DRC is not claimed here.
Open the ZIP in KiCad 9.0 and run ERC/DRC locally before GitHub replacement.

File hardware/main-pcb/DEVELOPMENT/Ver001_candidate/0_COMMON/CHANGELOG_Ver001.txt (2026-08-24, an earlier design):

SplitChoc64 Ver001 — COL2ROW normalization

Base: Ver000 FINAL_DIODE_POLARITY_FIX

- Standardized the matrix direction to COL2ROW.
- Fixed the embedded diode symbol graphic so its cathode bar is on pin 1 / K.
- Pin assignment remains 1=K, 2=A.
- Corrected embedded diode package metadata from SOD-123 to SOD-323.
- Audited all 64 PCB diodes:
    switch pad 1 -> ROW
    switch pad 2 -> diode pad 1 / K
    diode pad 2 / A -> COL
- Audited all 64 K silkscreen marks and SOD-323 3D model references.
- Existing copper routing was already electrically COL2ROW, so it was retained
  rather than unnecessarily rerouted.
- Firmware convention: diode-direction = "col2row".

No key/MCU/switch/joystick positions, Edge.Cuts, mounting holes or valid copper
geometry were changed.

No fresh KiCad ERC/DRC was run by ChatGPT after this update.
Run ERC and DRC on both sides before fabrication.

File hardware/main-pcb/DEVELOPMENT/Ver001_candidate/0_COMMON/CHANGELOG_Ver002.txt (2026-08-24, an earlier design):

SplitChoc64 Ver002
- Corrected malformed diode schematic graphic. COL2ROW electrical mapping unchanged.
- Ver001 ERC user-confirmed: LEFT 0/0, RIGHT 0/0.
- Ver001 DRC reports contained only diode K text-height warnings: LEFT 29, RIGHT 35.
- Increased all diode K silk text from 0.55 mm to 0.80 mm.
- Added B.SilkS K/bar to DLED1/DLED2 (pad1=GND=cathode).
- Added B.SilkS '+' next to battery connector pad1 (BAT_RAW) on J1/J2.
- Added SplitChoc64 logo to F.SilkS on both PCBs.
- Added B.SilkS outline to all 64 Choc hotswap sockets. Outline is derived from the actual
  kailh_choc_socket.step bottom outer contour, including its flowing spline shape, offset +0.20 mm.
- No copper, pads, tracks, key/switch coordinates, MCU coordinates, mounting holes, or Edge.Cuts changed.
- Fresh Ver002 ERC/DRC not run here. Please rerun both.

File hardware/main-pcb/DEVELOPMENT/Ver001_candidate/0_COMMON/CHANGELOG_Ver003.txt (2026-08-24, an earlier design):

SplitChoc64 Ver003

Fix from Ver002:
- Removed invalid hidden helper gr_text that caused KiCad PCB Editor parse failure.
- Removed unnecessary internal helper footprint properties introduced in Ver002.
- Kept all requested visible silkscreen:
  * diode K markers
  * blue LED K/bar markers
  * battery + markers
  * SplitChoc64 front logos
  * Choc socket flowing outlines
- Schematic files are unchanged from Ver002.
- Copper, pads, tracks, component coordinates, mounting holes and Edge.Cuts are unchanged.

User confirmed Ver002 schematic ERC LEFT/RIGHT = 0/0.
Fresh PCB DRC after Ver003 has not been run here.

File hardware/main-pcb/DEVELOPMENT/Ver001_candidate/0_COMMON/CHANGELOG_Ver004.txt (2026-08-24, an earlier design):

SplitChoc64 Ver004

Changes from Ver003:
- Replaced the Choc hotswap socket outline silk with a filled top-view projection.
- Projection is generated from the complete kailh_choc_socket.step 3D model, not the bottom face.
- Corrected the local Y orientation for B.Cu so the silk matches the actual 3D socket instead of
  appearing mirrored about the switch X axis.
- New socket graphic is B.SilkS solid filled polygons.
- Applied to all 29 LEFT + 35 RIGHT switch sockets.
- Diode/LED polarity silk, battery + marks, SplitChoc64 logos and all other Ver003 changes remain.
- No copper, pads, tracks, nets, switch/key positions, MCU positions, mounting holes, or Edge.Cuts changed.
- Schematics unchanged from Ver003 (user-confirmed ERC LEFT/RIGHT 0/0 before this PCB-only change).

Fresh Ver004 DRC has not been run by ChatGPT. Please run DRC on both boards.

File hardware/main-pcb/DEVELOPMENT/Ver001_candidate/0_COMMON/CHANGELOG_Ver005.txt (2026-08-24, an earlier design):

SplitChoc64 Ver005

Logo position adjustment only.

LEFT:
- from 80.000, 114.000
- to   60.000, 89.000
- move: left 20 mm, up 25 mm

RIGHT:
- from 260.000, 114.000
- to   280.000, 89.000
- move: right 20 mm, up 25 mm

No copper, pads, tracks, nets, components, Edge.Cuts, or any other silkscreen were changed.

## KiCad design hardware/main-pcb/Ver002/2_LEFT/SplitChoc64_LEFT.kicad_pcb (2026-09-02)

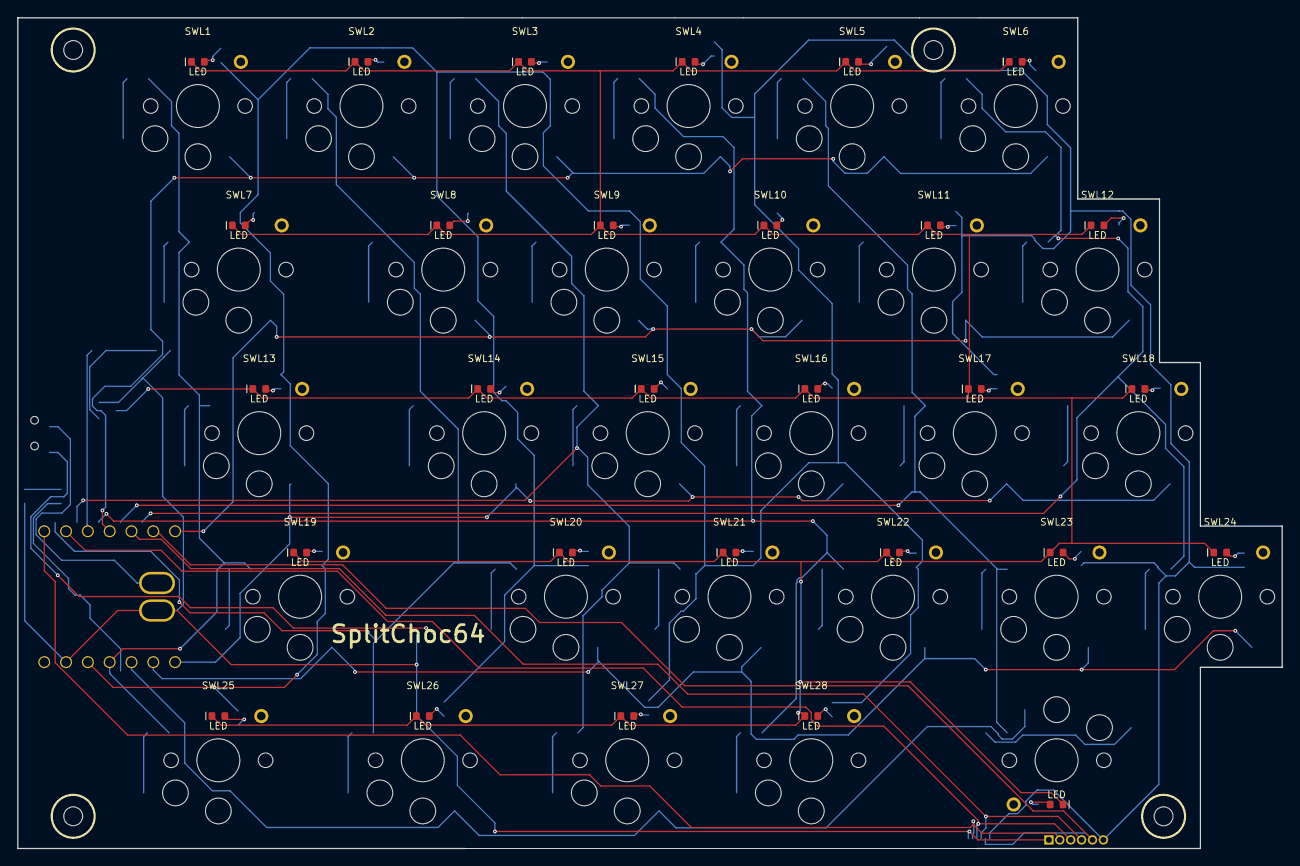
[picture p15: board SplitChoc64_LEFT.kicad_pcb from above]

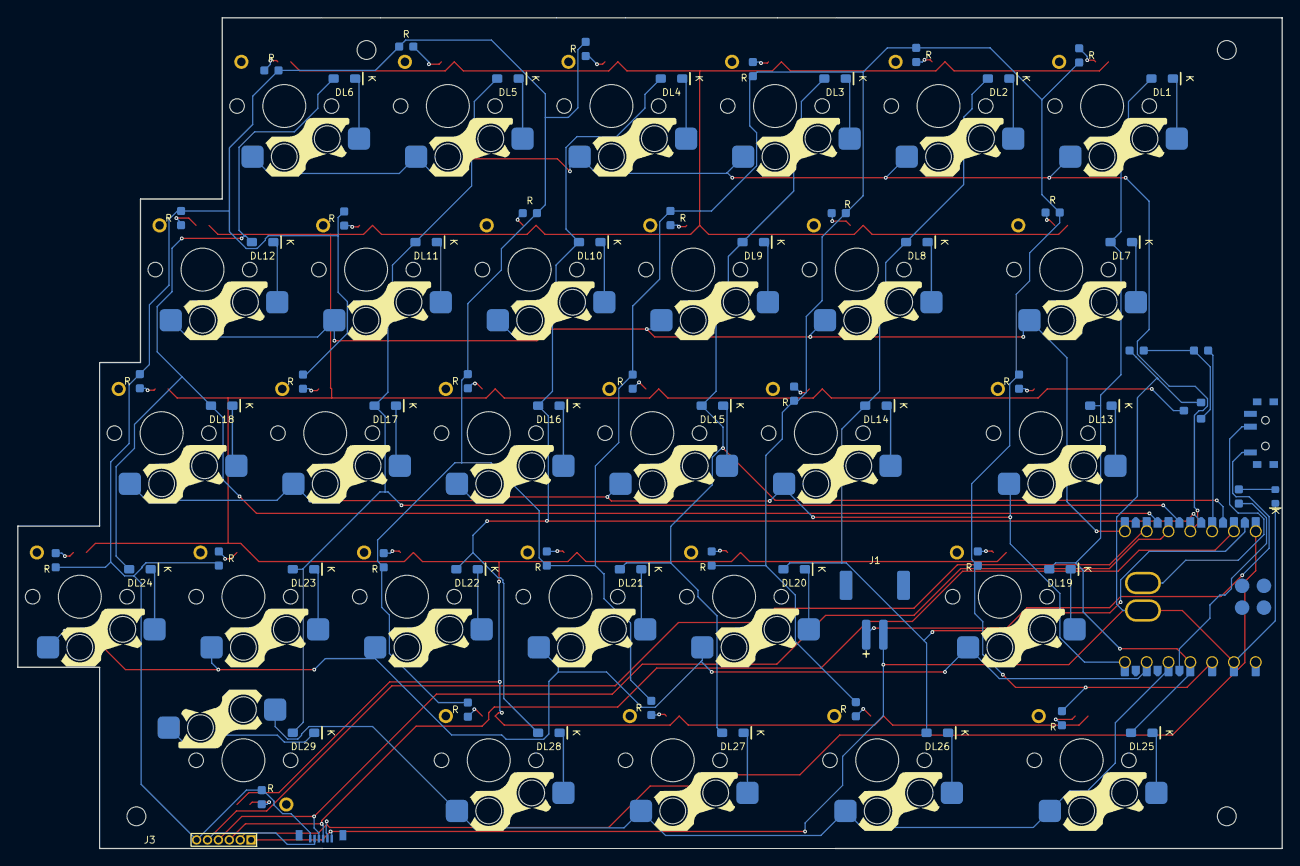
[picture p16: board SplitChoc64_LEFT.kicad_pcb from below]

Board: 2 copper layers, 147.3 x 96.8 mm, 130 parts (68 on the bottom side), 82 nets.

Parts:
DL1: 1N4148WS; DL1
DL2: 1N4148WS; DL2
DL3: 1N4148WS; DL3
DL4: 1N4148WS; DL4
DL5: 1N4148WS; DL5
DL6: 1N4148WS; DL6
DL7: 1N4148WS; DL7
DL8: 1N4148WS; DL8
DL9: 1N4148WS; DL9
DL10: 1N4148WS; DL10
DL11: 1N4148WS; DL11
DL12: 1N4148WS; DL12
DL13: 1N4148WS; DL13
DL14: 1N4148WS; DL14
DL15: 1N4148WS; DL15
DL16: 1N4148WS; DL16
DL17: 1N4148WS; DL17
DL18: 1N4148WS; DL18
DL19: 1N4148WS; DL19
DL20: 1N4148WS; DL20
DL21: 1N4148WS; DL21
DL22: 1N4148WS; DL22
DL23: 1N4148WS; DL23
DL24: 1N4148WS; DL24
DL25: 1N4148WS; DL25
DL26: 1N4148WS; DL26
DL27: 1N4148WS; DL27
DL28: 1N4148WS; DL28
DL29: 1N4148WS; DL29
DLED1: KT-0603B; LED_0603_TOP_BLUE
H1, H2, H3, H4: M2_CASE_MOUNT
J1: S2B-PH-SM4-TB; JST_PH_S2B-PH-SM4-TB_1x02-1MP_P2.00mm_Horizontal
J3: GND EXT_A EXT_B EXT_SDA EXT_SCL 3V3; J3
J5: FH19C-6S-0.5SH(10); FH19C-6S-0.5SH_HandSolder
LEDL1, LEDL2, LEDL3, LEDL4, LEDL5, LEDL6, LEDL7, LEDL8, LEDL9, LEDL10, LEDL11, LEDL12, LEDL13, LEDL14, LEDL15, LEDL16, LEDL17, LEDL18, LEDL19, LEDL20, LEDL21, LEDL22, LEDL23, LEDL24, LEDL25, LEDL26, LEDL27, LEDL28, LEDL29: SMLD12WBN1W1; SMLD12WBN1W1_0603
QBL1: 2N7002; SOT-23
RBLL1, RBLL2, RBLL3, RBLL4, RBLL5, RBLL6, RBLL7, RBLL8, RBLL9, RBLL10, RBLL11, RBLL12, RBLL13, RBLL14, RBLL15, RBLL16, RBLL17, RBLL18, RBLL19, RBLL20, RBLL21, RBLL22, RBLL23, RBLL24, RBLL25, RBLL26, RBLL27, RBLL28, RBLL29: 1k; STATUS_R_0603
RGBL1: 1k; STATUS_R_0603
RLED1: 100R; STATUS_R_0603
RPDL1: 100k; STATUS_R_0603
SWL1: Kailh Choc V2 / HotSwap; SWL1
SWL2: Kailh Choc V2 / HotSwap; SWL2
SWL3: Kailh Choc V2 / HotSwap; SWL3
SWL4: Kailh Choc V2 / HotSwap; SWL4
SWL5: Kailh Choc V2 / HotSwap; SWL5
SWL6: Kailh Choc V2 / HotSwap; SWL6
SWL7: Kailh Choc V2 / HotSwap; SWL7
SWL8: Kailh Choc V2 / HotSwap; SWL8
SWL9: Kailh Choc V2 / HotSwap; SWL9
SWL10: Kailh Choc V2 / HotSwap; SWL10
SWL11: Kailh Choc V2 / HotSwap; SWL11
SWL12: Kailh Choc V2 / HotSwap; SWL12
SWL13: Kailh Choc V2 / HotSwap; SWL13
SWL14: Kailh Choc V2 / HotSwap; SWL14
SWL15: Kailh Choc V2 / HotSwap; SWL15
SWL16: Kailh Choc V2 / HotSwap; SWL16
SWL17: Kailh Choc V2 / HotSwap; SWL17
SWL18: Kailh Choc V2 / HotSwap; SWL18
SWL19: Kailh Choc V2 / HotSwap; SWL19
SWL20: Kailh Choc V2 / HotSwap; SWL20
SWL21: Kailh Choc V2 / HotSwap; SWL21
SWL22: Kailh Choc V2 / HotSwap; SWL22
SWL23: Kailh Choc V2 / HotSwap; SWL23
SWL24: Kailh Choc V2 / HotSwap; SWL24
SWL25: Kailh Choc V2 / HotSwap; SWL25
SWL26: Kailh Choc V2 / HotSwap; SWL26
SWL27: Kailh Choc V2 / HotSwap; SWL27
SWL28: Kailh Choc V2 / HotSwap; SWL28
SWL29: Kailh Choc V2 / HotSwap; SWL29
SWP1: PCM12SMTR; SWP1
U1: XIAO nRF52840 Plus; U1

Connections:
L_3V3: J3.6, J5.6, RBLL1.1, RBLL2.1, RBLL3.1, RBLL4.1, RBLL5.1, RBLL6.1, RBLL7.1, RBLL8.1, RBLL9.1, RBLL10.1, RBLL11.1, RBLL12.1, RBLL13.1, RBLL14.1, RBLL15.1, RBLL16.1, RBLL17.1, RBLL18.1, RBLL19.1, RBLL20.1, RBLL21.1, RBLL22.1, RBLL23.1, RBLL24.1, RBLL25.1, RBLL26.1, RBLL27.1, RBLL28.1, RBLL29.1, U1.12
L_BAT_RAW: J1.1, SWP1.1
L_BAT_SW: SWP1.2, U1.28, U1.32
L_BL_GATE: QBL1.1, RGBL1.2, RPDL1.1
L_BL_LED_A1: LEDL1.2, RBLL1.2
L_BL_LED_A2: LEDL2.2, RBLL2.2
L_BL_LED_A3: LEDL3.2, RBLL3.2
L_BL_LED_A4: LEDL4.2, RBLL4.2
L_BL_LED_A5: LEDL5.2, RBLL5.2
L_BL_LED_A6: LEDL6.2, RBLL6.2
L_BL_LED_A7: LEDL7.2, RBLL7.2
L_BL_LED_A8: LEDL8.2, RBLL8.2
L_BL_LED_A9: LEDL9.2, RBLL9.2
L_BL_LED_A10: LEDL10.2, RBLL10.2
L_BL_LED_A11: LEDL11.2, RBLL11.2
L_BL_LED_A12: LEDL12.2, RBLL12.2
L_BL_LED_A13: LEDL13.2, RBLL13.2
L_BL_LED_A14: LEDL14.2, RBLL14.2
L_BL_LED_A15: LEDL15.2, RBLL15.2
L_BL_LED_A16: LEDL16.2, RBLL16.2
L_BL_LED_A17: LEDL17.2, RBLL17.2
L_BL_LED_A18: LEDL18.2, RBLL18.2
L_BL_LED_A19: LEDL19.2, RBLL19.2
L_BL_LED_A20: LEDL20.2, RBLL20.2
L_BL_LED_A21: LEDL21.2, RBLL21.2
L_BL_LED_A22: LEDL22.2, RBLL22.2
L_BL_LED_A23: LEDL23.2, RBLL23.2
L_BL_LED_A24: LEDL24.2, RBLL24.2
L_BL_LED_A25: LEDL25.2, RBLL25.2
L_BL_LED_A26: LEDL26.2, RBLL26.2
L_BL_LED_A27: LEDL27.2, RBLL27.2
L_BL_LED_A28: LEDL28.2, RBLL28.2
L_BL_LED_A29: LEDL29.2, RBLL29.2
L_BL_LED_RETURN: LEDL1.1, LEDL2.1, LEDL3.1, LEDL4.1, LEDL5.1, LEDL6.1, LEDL7.1, LEDL8.1, LEDL9.1, LEDL10.1, LEDL11.1, LEDL12.1, LEDL13.1, LEDL14.1, LEDL15.1, LEDL16.1, LEDL17.1, LEDL18.1, LEDL19.1, LEDL20.1, LEDL21.1, LEDL22.1, LEDL23.1, LEDL24.1, LEDL25.1, LEDL26.1, LEDL27.1, LEDL28.1, LEDL29.1, QBL1.3
L_BL_PWM: RGBL1.1, U1.3
L_COL0: DL1.2, DL7.2, DL13.2, DL19.2, DL25.2, U1.11
L_COL1: DL2.2, DL8.2, DL14.2, DL20.2, DL26.2, U1.15
L_COL2: DL3.2, DL9.2, DL15.2, DL21.2, DL27.2, U1.16
L_COL3: DL4.2, DL10.2, DL16.2, DL22.2, DL28.2, U1.17
L_COL4: DL5.2, DL11.2, DL17.2, DL23.2, DL29.2, U1.18
L_COL5: DL6.2, DL12.2, DL18.2, DL24.2, U1.19
L_EXT_A: J3.2, J5.2, U1.1
L_EXT_B: J3.3, J5.3, U1.2
L_EXT_SCL: J3.5, J5.5, U1.6
L_EXT_SDA: J3.4, J5.4, U1.5
L_GND: DLED1.1, J1.2, J3.1, J5.1, QBL1.2, RPDL1.2, U1.13, U1.29, U1.33
L_K1_D: DL1.1, SWL1.2
L_K2_D: DL2.1, SWL2.2
L_K3_D: DL3.1, SWL3.2
L_K4_D: DL4.1, SWL4.2
L_K5_D: DL5.1, SWL5.2
L_K6_D: DL6.1, SWL6.2
L_K7_D: DL7.1, SWL7.2
L_K8_D: DL8.1, SWL8.2
L_K9_D: DL9.1, SWL9.2
L_K10_D: DL10.1, SWL10.2
L_K11_D: DL11.1, SWL11.2
L_K12_D: DL12.1, SWL12.2
L_K13_D: DL13.1, SWL13.2
L_K14_D: DL14.1, SWL14.2
L_K15_D: DL15.1, SWL15.2
L_K16_D: DL16.1, SWL16.2
L_K17_D: DL17.1, SWL17.2
L_K18_D: DL18.1, SWL18.2
L_K19_D: DL19.1, SWL19.2
L_K20_D: DL20.1, SWL20.2
L_K21_D: DL21.1, SWL21.2
L_K22_D: DL22.1, SWL22.2
L_K23_D: DL23.1, SWL23.2
L_K24_D: DL24.1, SWL24.2
L_K25_D: DL25.1, SWL25.2
L_K26_D: DL26.1, SWL26.2
L_K27_D: DL27.1, SWL27.2
L_K28_D: DL28.1, SWL28.2
L_K29_D: DL29.1, SWL29.2
L_LED_A: DLED1.2, RLED1.2
L_LED_CTRL: RLED1.1, U1.23
L_ROW0: SWL1.1, SWL2.1, SWL3.1, SWL4.1, SWL5.1, SWL6.1, U1.4
L_ROW1: SWL7.1, SWL8.1, SWL9.1, SWL10.1, SWL11.1, SWL12.1, U1.7
L_ROW2: SWL13.1, SWL14.1, SWL15.1, SWL16.1, SWL17.1, SWL18.1, U1.8
L_ROW3: SWL19.1, SWL20.1, SWL21.1, SWL22.1, SWL23.1, SWL24.1, U1.9
L_ROW4: SWL25.1, SWL26.1, SWL27.1, SWL28.1, SWL29.1, U1.10

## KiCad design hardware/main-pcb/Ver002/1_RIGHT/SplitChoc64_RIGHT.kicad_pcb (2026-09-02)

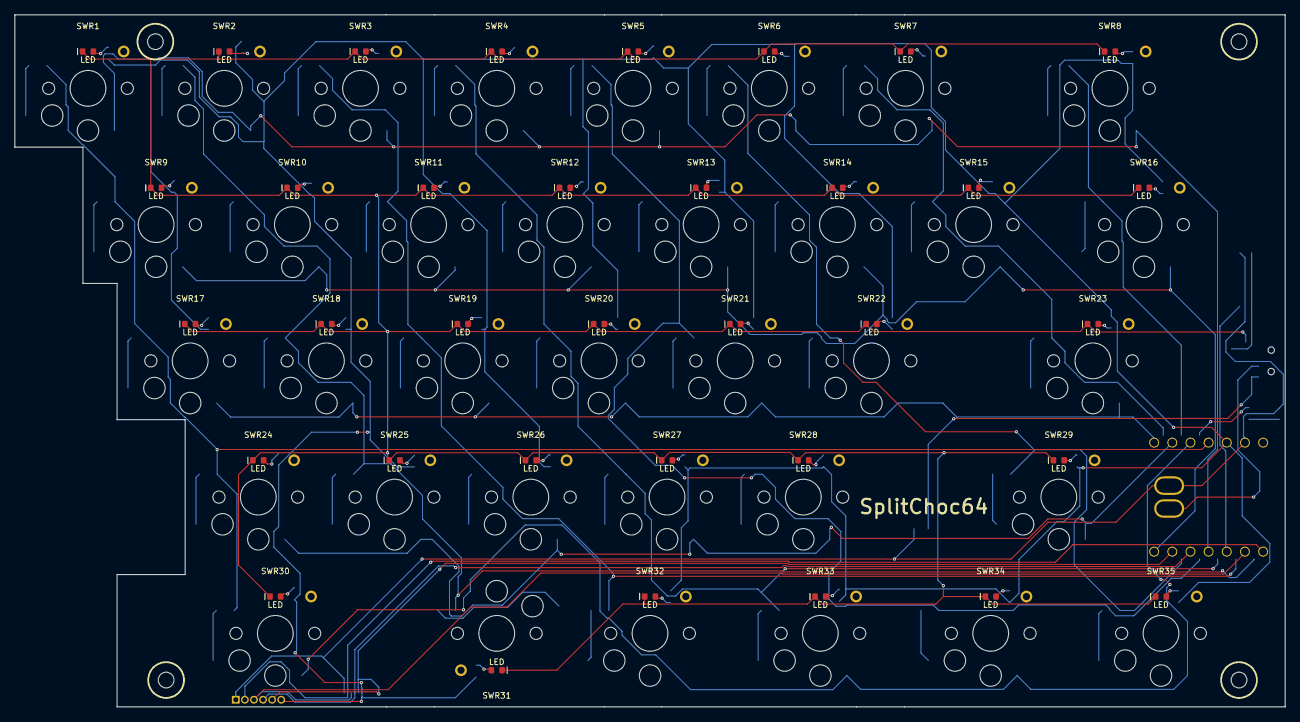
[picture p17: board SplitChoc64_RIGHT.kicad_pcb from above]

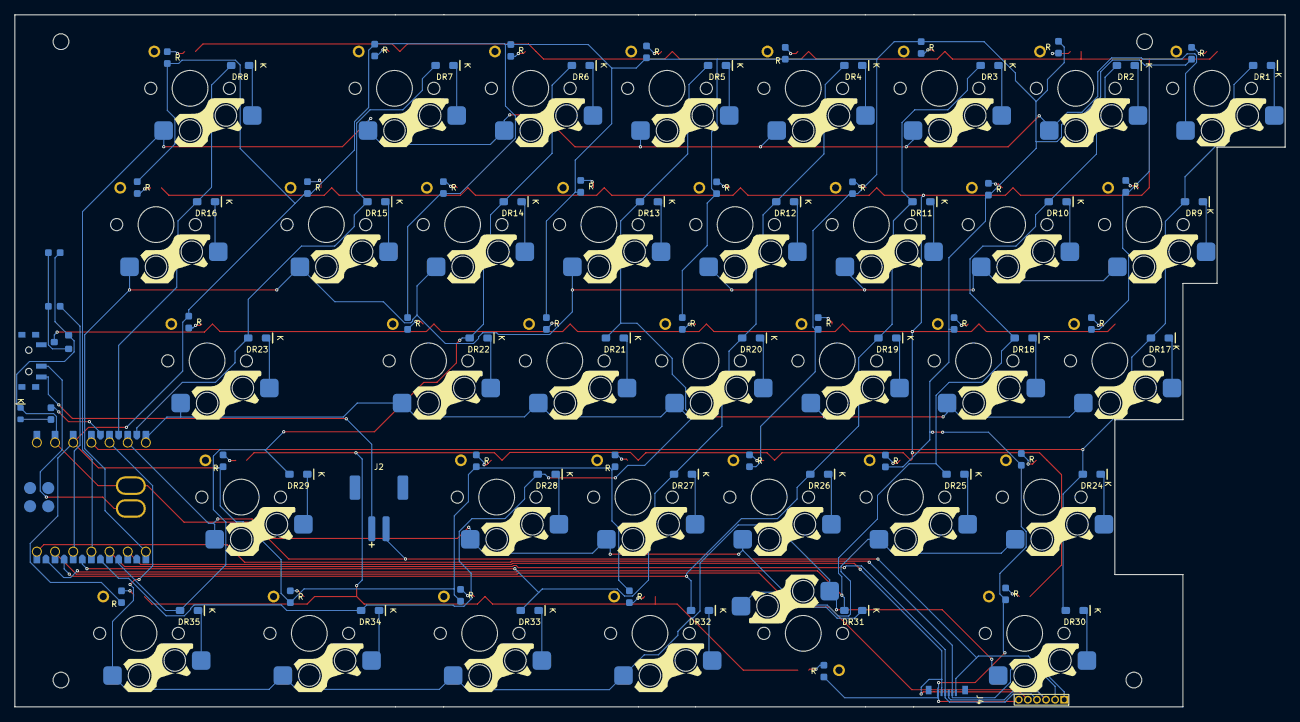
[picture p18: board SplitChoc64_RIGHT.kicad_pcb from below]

Board: 2 copper layers, 177.6 x 96.8 mm, 154 parts (80 on the bottom side), 96 nets.

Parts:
DLED2: KT-0603B; LED_0603_TOP_BLUE
DR1: 1N4148WS; DR1
DR2: 1N4148WS; DR2
DR3: 1N4148WS; DR3
DR4: 1N4148WS; DR4
DR5: 1N4148WS; DR5
DR6: 1N4148WS; DR6
DR7: 1N4148WS; DR7
DR8: 1N4148WS; DR8
DR9: 1N4148WS; DR9
DR10: 1N4148WS; DR10
DR11: 1N4148WS; DR11
DR12: 1N4148WS; DR12
DR13: 1N4148WS; DR13
DR14: 1N4148WS; DR14
DR15: 1N4148WS; DR15
DR16: 1N4148WS; DR16
DR17: 1N4148WS; DR17
DR18: 1N4148WS; DR18
DR19: 1N4148WS; DR19
DR20: 1N4148WS; DR20
DR21: 1N4148WS; DR21
DR22: 1N4148WS; DR22
DR23: 1N4148WS; DR23
DR24: 1N4148WS; DR24
DR25: 1N4148WS; DR25
DR26: 1N4148WS; DR26
DR27: 1N4148WS; DR27
DR28: 1N4148WS; DR28
DR29: 1N4148WS; DR29
DR30: 1N4148WS; DR30
DR31: 1N4148WS; DR31
DR32: 1N4148WS; DR32
DR33: 1N4148WS; DR33
DR34: 1N4148WS; DR34
DR35: 1N4148WS; DR35
J2: S2B-PH-SM4-TB; JST_PH_S2B-PH-SM4-TB_1x02-1MP_P2.00mm_Horizontal
J4: GND EXT_A EXT_B EXT_SDA EXT_SCL 3V3; J4
J6: FH19C-6S-0.5SH(10); FH19C-6S-0.5SH_HandSolder
LEDR1, LEDR2, LEDR3, LEDR4, LEDR5, LEDR6, LEDR7, LEDR8, LEDR9, LEDR10, LEDR11, LEDR12, LEDR13, LEDR14, LEDR15, LEDR16, LEDR17, LEDR18, LEDR19, LEDR20, LEDR21, LEDR22, LEDR23, LEDR24, LEDR25, LEDR26, LEDR27, LEDR28, LEDR29, LEDR30, LEDR31, LEDR32, LEDR33, LEDR34, LEDR35: SMLD12WBN1W1; SMLD12WBN1W1_0603
QBL2: 2N7002; SOT-23
RBLR1, RBLR2, RBLR3, RBLR4, RBLR5, RBLR6, RBLR7, RBLR8, RBLR9, RBLR10, RBLR11, RBLR12, RBLR13, RBLR14, RBLR15, RBLR16, RBLR17, RBLR18, RBLR19, RBLR20, RBLR21, RBLR22, RBLR23, RBLR24, RBLR25, RBLR26, RBLR27, RBLR28, RBLR29, RBLR30, RBLR31, RBLR32, RBLR33, RBLR34, RBLR35: 1k; STATUS_R_0603
RGBL2: 1k; STATUS_R_0603
RLED2: 100R; STATUS_R_0603
RPDR2: 100k; STATUS_R_0603
R_H1, R_H2, R_H3, R_H4: M2_CASE_MOUNT
SWP2: PCM12SMTR; SWP2
SWR1: Kailh Choc V2 / HotSwap; SWR1
SWR2: Kailh Choc V2 / HotSwap; SWR2
SWR3: Kailh Choc V2 / HotSwap; SWR3
SWR4: Kailh Choc V2 / HotSwap; SWR4
SWR5: Kailh Choc V2 / HotSwap; SWR5
SWR6: Kailh Choc V2 / HotSwap; SWR6
SWR7: Kailh Choc V2 / HotSwap; SWR7
SWR8: Kailh Choc V2 / HotSwap; SWR8
SWR9: Kailh Choc V2 / HotSwap; SWR9
SWR10: Kailh Choc V2 / HotSwap; SWR10
SWR11: Kailh Choc V2 / HotSwap; SWR11
SWR12: Kailh Choc V2 / HotSwap; SWR12
SWR13: Kailh Choc V2 / HotSwap; SWR13
SWR14: Kailh Choc V2 / HotSwap; SWR14
SWR15: Kailh Choc V2 / HotSwap; SWR15
SWR16: Kailh Choc V2 / HotSwap; SWR16
SWR17: Kailh Choc V2 / HotSwap; SWR17
SWR18: Kailh Choc V2 / HotSwap; SWR18
SWR19: Kailh Choc V2 / HotSwap; SWR19
SWR20: Kailh Choc V2 / HotSwap; SWR20
SWR21: Kailh Choc V2 / HotSwap; SWR21
SWR22: Kailh Choc V2 / HotSwap; SWR22
SWR23: Kailh Choc V2 / HotSwap; SWR23
SWR24: Kailh Choc V2 / HotSwap; SWR24
SWR25: Kailh Choc V2 / HotSwap; SWR25
SWR26: Kailh Choc V2 / HotSwap; SWR26
SWR27: Kailh Choc V2 / HotSwap; SWR27
SWR28: Kailh Choc V2 / HotSwap; SWR28
SWR29: Kailh Choc V2 / HotSwap; SWR29
SWR30: Kailh Choc V2 / HotSwap; SWR30
SWR31: Kailh Choc V2 / HotSwap; SWR31
SWR32: Kailh Choc V2 / HotSwap; SWR32
SWR33: Kailh Choc V2 / HotSwap; SWR33
SWR34: Kailh Choc V2 / HotSwap; SWR34
SWR35: Kailh Choc V2 / HotSwap; SWR35
U2: XIAO nRF52840 Plus; U2

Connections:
R_3V3: J4.6, J6.6, RBLR1.1, RBLR2.1, RBLR3.1, RBLR4.1, RBLR5.1, RBLR6.1, RBLR7.1, RBLR8.1, RBLR9.1, RBLR10.1, RBLR11.1, RBLR12.1, RBLR13.1, RBLR14.1, RBLR15.1, RBLR16.1, RBLR17.1, RBLR18.1, RBLR19.1, RBLR20.1, RBLR21.1, RBLR22.1, RBLR23.1, RBLR24.1, RBLR25.1, RBLR26.1, RBLR27.1, RBLR28.1, RBLR29.1, RBLR30.1, RBLR31.1, RBLR32.1, RBLR33.1, RBLR34.1, RBLR35.1, U2.12
R_BAT_RAW: J2.1, SWP2.3
R_BAT_SW: SWP2.2, U2.28, U2.32
R_BL_GATE: QBL2.1, RGBL2.2, RPDR2.1
R_BL_LED_A1: LEDR1.2, RBLR1.2
R_BL_LED_A2: LEDR2.2, RBLR2.2
R_BL_LED_A3: LEDR3.2, RBLR3.2
R_BL_LED_A4: LEDR4.2, RBLR4.2
R_BL_LED_A5: LEDR5.2, RBLR5.2
R_BL_LED_A6: LEDR6.2, RBLR6.2
R_BL_LED_A7: LEDR7.2, RBLR7.2
R_BL_LED_A8: LEDR8.2, RBLR8.2
R_BL_LED_A9: LEDR9.2, RBLR9.2
R_BL_LED_A10: LEDR10.2, RBLR10.2
R_BL_LED_A11: LEDR11.2, RBLR11.2
R_BL_LED_A12: LEDR12.2, RBLR12.2
R_BL_LED_A13: LEDR13.2, RBLR13.2
R_BL_LED_A14: LEDR14.2, RBLR14.2
R_BL_LED_A15: LEDR15.2, RBLR15.2
R_BL_LED_A16: LEDR16.2, RBLR16.2
R_BL_LED_A17: LEDR17.2, RBLR17.2
R_BL_LED_A18: LEDR18.2, RBLR18.2
R_BL_LED_A19: LEDR19.2, RBLR19.2
R_BL_LED_A20: LEDR20.2, RBLR20.2
R_BL_LED_A21: LEDR21.2, RBLR21.2
R_BL_LED_A22: LEDR22.2, RBLR22.2
R_BL_LED_A23: LEDR23.2, RBLR23.2
R_BL_LED_A24: LEDR24.2, RBLR24.2
R_BL_LED_A25: LEDR25.2, RBLR25.2
R_BL_LED_A26: LEDR26.2, RBLR26.2
R_BL_LED_A27: LEDR27.2, RBLR27.2
R_BL_LED_A28: LEDR28.2, RBLR28.2
R_BL_LED_A29: LEDR29.2, RBLR29.2
R_BL_LED_A30: LEDR30.2, RBLR30.2
R_BL_LED_A31: LEDR31.2, RBLR31.2
R_BL_LED_A32: LEDR32.2, RBLR32.2
R_BL_LED_A33: LEDR33.2, RBLR33.2
R_BL_LED_A34: LEDR34.2, RBLR34.2
R_BL_LED_A35: LEDR35.2, RBLR35.2
R_BL_LED_RETURN: LEDR1.1, LEDR2.1, LEDR3.1, LEDR4.1, LEDR5.1, LEDR6.1, LEDR7.1, LEDR8.1, LEDR9.1, LEDR10.1, LEDR11.1, LEDR12.1, LEDR13.1, LEDR14.1, LEDR15.1, LEDR16.1, LEDR17.1, LEDR18.1, LEDR19.1, LEDR20.1, LEDR21.1, LEDR22.1, LEDR23.1, LEDR24.1, LEDR25.1, LEDR26.1, LEDR27.1, LEDR28.1, LEDR29.1, LEDR30.1, LEDR31.1, LEDR32.1, LEDR33.1, LEDR34.1, LEDR35.1, QBL2.3
R_BL_PWM: RGBL2.1, U2.3
R_COL0: DR1.2, DR9.2, DR17.2, DR24.2, DR30.2, U2.11
R_COL1: DR2.2, DR10.2, DR18.2, DR25.2, DR31.2, U2.15
R_COL2: DR3.2, DR11.2, DR19.2, DR26.2, DR32.2, U2.16
R_COL3: DR4.2, DR12.2, DR20.2, DR27.2, DR33.2, U2.17
R_COL4: DR5.2, DR13.2, DR21.2, DR28.2, DR34.2, U2.18
R_COL5: DR6.2, DR14.2, DR22.2, DR29.2, DR35.2, U2.19
R_COL6: DR7.2, DR15.2, DR23.2, U2.21
R_COL7: DR8.2, DR16.2, U2.22
R_EXT_A: J4.2, J6.2, U2.1
R_EXT_B: J4.3, J6.3, U2.2
R_EXT_SCL: J4.5, J6.5, U2.6
R_EXT_SDA: J4.4, J6.4, U2.5
R_GND: DLED2.1, J2.2, J4.1, J6.1, QBL2.2, RPDR2.2, U2.13, U2.29, U2.33
R_K1_D: DR1.1, SWR1.2
R_K2_D: DR2.1, SWR2.2
R_K3_D: DR3.1, SWR3.2
R_K4_D: DR4.1, SWR4.2
R_K5_D: DR5.1, SWR5.2
R_K6_D: DR6.1, SWR6.2
R_K7_D: DR7.1, SWR7.2
R_K8_D: DR8.1, SWR8.2
R_K9_D: DR9.1, SWR9.2
R_K10_D: DR10.1, SWR10.2
R_K11_D: DR11.1, SWR11.2
R_K12_D: DR12.1, SWR12.2
R_K13_D: DR13.1, SWR13.2
R_K14_D: DR14.1, SWR14.2
R_K15_D: DR15.1, SWR15.2
R_K16_D: DR16.1, SWR16.2
R_K17_D: DR17.1, SWR17.2
R_K18_D: DR18.1, SWR18.2
R_K19_D: DR19.1, SWR19.2
R_K20_D: DR20.1, SWR20.2
R_K21_D: DR21.1, SWR21.2
R_K22_D: DR22.1, SWR22.2
R_K23_D: DR23.1, SWR23.2
R_K24_D: DR24.1, SWR24.2
R_K25_D: DR25.1, SWR25.2
R_K26_D: DR26.1, SWR26.2
R_K27_D: DR27.1, SWR27.2
R_K28_D: DR28.1, SWR28.2
R_K29_D: DR29.1, SWR29.2
R_K30_D: DR30.1, SWR30.2
R_K31_D: DR31.1, SWR31.2
R_K32_D: DR32.1, SWR32.2
R_K33_D: DR33.1, SWR33.2
R_K34_D: DR34.1, SWR34.2
R_K35_D: DR35.1, SWR35.2
R_LED_A: DLED2.2, RLED2.2
R_LED_CTRL: RLED2.1, U2.23
R_ROW0: SWR1.1, SWR2.1, SWR3.1, SWR4.1, SWR5.1, SWR6.1, SWR7.1, SWR8.1, U2.4
R_ROW1: SWR9.1, SWR10.1, SWR11.1, SWR12.1, SWR13.1, SWR14.1, SWR15.1, SWR16.1, U2.7
R_ROW2: SWR17.1, SWR18.1, SWR19.1, SWR20.1, SWR21.1, SWR22.1, SWR23.1, U2.8
R_ROW3: SWR24.1, SWR25.1, SWR26.1, SWR27.1, SWR28.1, SWR29.1, U2.9
R_ROW4: SWR30.1, SWR31.1, SWR32.1, SWR33.1, SWR34.1, SWR35.1, U2.10

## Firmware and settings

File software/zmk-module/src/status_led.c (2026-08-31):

#include <errno.h>
#include <stdbool.h>

#include <zephyr/device.h>
#include <zephyr/devicetree.h>
#include <zephyr/drivers/gpio.h>
#include <zephyr/init.h>
#include <zephyr/kernel.h>

#include <zmk/event_manager.h>

#define STATUS_LED_NODE DT_ALIAS(status_led)

#if DT_NODE_EXISTS(STATUS_LED_NODE)

static const struct gpio_dt_spec status_led = GPIO_DT_SPEC_GET(STATUS_LED_NODE, gpios);
static struct k_work_delayable status_led_work;
static bool status_led_on;
static uint32_t blink_period_ms;

static void status_led_set(bool on)
{
    status_led_on = on;
    gpio_pin_set_dt(&status_led, on ? 1 : 0);
}

static void status_led_work_handler(struct k_work *work)
{
    ARG_UNUSED(work);

    if (blink_period_ms == 0U) {
        return;
    }

    status_led_set(!status_led_on);
    k_work_reschedule(&status_led_work, K_MSEC(blink_period_ms));
}

static void status_led_apply(bool solid_on, uint32_t period_ms)
{
    blink_period_ms = period_ms;
    k_work_cancel_delayable(&status_led_work);

    if (period_ms == 0U) {
        status_led_set(solid_on);
        return;
    }

    status_led_set(true);
    k_work_reschedule(&status_led_work, K_MSEC(period_ms));
}

#if defined(CONFIG_ZMK_SPLIT_ROLE_CENTRAL)

#include <zmk/ble.h>
#include <zmk/endpoints.h>
#include <zmk/events/ble_active_profile_changed.h>
#include <zmk/events/endpoint_changed.h>

/*
 * Central / host-facing RIGHT LED policy:
 *   solid ON       = USB or BLE host connected
 *   slow blink 1 s = bonded BLE profile selected but currently disconnected
 *   fast blink 250 ms = open BLE profile / pairing-ready state
 *   OFF            = no usable endpoint state
 */
static void status_led_update_central(void)
{
    struct zmk_endpoint_instance selected = zmk_endpoint_get_selected();

    if (selected.transport == ZMK_TRANSPORT_USB) {
        status_led_apply(true, 0U);
        return;
    }

    if (selected.transport == ZMK_TRANSPORT_BLE && zmk_ble_active_profile_is_connected()) {
        status_led_apply(true, 0U);
        return;
    }

    if (zmk_endpoint_get_preferred_transport() == ZMK_TRANSPORT_BLE) {
        if (zmk_ble_active_profile_is_open()) {
            status_led_apply(false, 250U);
        } else {
            status_led_apply(false, 1000U);
        }
        return;
    }

    status_led_apply(false, 0U);
}

static int status_led_endpoint_listener(const zmk_event_t *eh)
{
    ARG_UNUSED(eh);
    status_led_update_central();
    return ZMK_EV_EVENT_BUBBLE;
}

ZMK_LISTENER(splitchoc64_status_led_endpoint, status_led_endpoint_listener);
ZMK_SUBSCRIPTION(splitchoc64_status_led_endpoint, zmk_endpoint_changed);
#if defined(CONFIG_ZMK_BLE)
ZMK_SUBSCRIPTION(splitchoc64_status_led_endpoint, zmk_ble_active_profile_changed);
#endif

#else

#include <zmk/events/split_peripheral_status_changed.h>
#include <zmk/split/bluetooth/peripheral.h>

/*
 * Peripheral LEFT LED policy:
 *   solid ON       = split link to RIGHT central established
 *   slow blink 1 s = waiting for the central half
 */
static void status_led_update_peripheral(void)
{
    if (zmk_split_bt_peripheral_is_connected()) {
        status_led_apply(true, 0U);
    } else {
        status_led_apply(false, 1000U);
    }
}

static int status_led_peripheral_listener(const zmk_event_t *eh)
{
    ARG_UNUSED(eh);
    status_led_update_peripheral();
    return ZMK_EV_EVENT_BUBBLE;
}

ZMK_LISTENER(splitchoc64_status_led_peripheral, status_led_peripheral_listener);
ZMK_SUBSCRIPTION(splitchoc64_status_led_peripheral, zmk_split_peripheral_status_changed);

#endif

static int splitchoc64_status_led_init(void)
{
    int ret;

    if (!gpio_is_ready_dt(&status_led)) {
        return -ENODEV;
    }

    ret = gpio_pin_configure_dt(&status_led, GPIO_OUTPUT_INACTIVE);
    if (ret < 0) {
        return ret;
    }

    k_work_init_delayable(&status_led_work, status_led_work_handler);

#if defined(CONFIG_ZMK_SPLIT_ROLE_CENTRAL)
    status_led_update_central();
#else
    status_led_update_peripheral();
#endif

    return 0;
}

SYS_INIT(splitchoc64_status_led_init, APPLICATION, 90);

#endif

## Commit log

2026-08-22 Replace RC history with current SplitChoc64 firmware README
2026-08-22 Replace obsolete RC validator with current architecture validation
2026-08-24 Unify repository as SplitChoc64
    Add unified hardware/firmware project structure while preserving the current validated ZMK root layout.
2026-08-24 Import Trackball Add-on Ver003 sources
    Import finalized Trackball Add-on Ver003 KiCad sources, documentation, validation metadata, and authoritative 3D asset hashes.
    [BOM.csv, PINMAP.csv, SplitChoc64_FFC_Adapter.kicad_pcb]
2026-08-24 Extract Ver012 production source archive
    [BM02B_SRSS_TB_PROXY.step, COL2ROW_AUDIT_Ver001.csv, LED_0603_1608_TOP_PROXY.step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]
2026-08-24 Organize Ver012 production data
    [BM02B_SRSS_TB_PROXY.step, COL2ROW_AUDIT_Ver001.csv, LED_0603_1608_TOP_PROXY.step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]
2026-08-24 Relabel first production hardware baseline as Ver000
    [BM02B_SRSS_TB_PROXY.step, COL2ROW_AUDIT_Ver001.csv, LED_0603_1608_TOP_PROXY.step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]
2026-08-24 Relabel trackball add-on baseline as Ver000
    [BOM.csv, PINMAP.csv, SplitChoc64_FFC_Adapter.kicad_pcb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]
2026-08-24 Add workflow to stage Ver001 development candidate
2026-08-24 Add Ver001 development candidate package [skip ci]
    [BM02B_SRSS_TB_PROXY.step, COL2ROW_AUDIT_Ver001.csv, LED_0603_1608_TOP_PROXY.step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]
2026-08-24 Stage DRC 0/0 Ver001 development checkpoint
    [BM02B_SRSS_TB_PROXY.step, LED_0603_1608_TOP_PROXY.step, R_0603_1608_PROXY.step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]
2026-08-24 Apply and validate parallel trackball FFC connectors
2026-08-24 Stage parallel FFC changes for local DRC review
2026-08-24 Stage parallel trackball FFC connectors in Ver001
    [SplitChoc64_LEFT.kicad_pcb, SplitChoc64_RIGHT.kicad_pcb]
2026-08-24 Run KiCad 9 DRC on staged Ver001 FFC changes
2026-08-24 Publish staged FFC KiCad DRC report
2026-08-24 Repair FFC fanout and rerun KiCad DRC
2026-08-24 Repair parallel FFC fanout and publish DRC pass 2
    [SplitChoc64_LEFT.kicad_pcb, SplitChoc64_RIGHT.kicad_pcb]
2026-08-24 Repair parallel FFC direct fanout
    [SplitChoc64_LEFT.kicad_pcb, SplitChoc64_RIGHT.kicad_pcb]
2026-08-24 Publish repaired FFC KiCad DRC report
2026-08-24 Route FFC fanout into spaced JOY trace sections
2026-08-24 Rebuild clean Ver001 FFC footprint placement and DRC
    [SplitChoc64_LEFT.kicad_pcb, SplitChoc64_RIGHT.kicad_pcb]
2026-08-24 Route FFC power nets and validate with KiCad
2026-08-24 Route Ver001 FFC power nets and publish DRC
    [SplitChoc64_LEFT.kicad_pcb, SplitChoc64_RIGHT.kicad_pcb]
2026-08-24 Restore footprint-only FFC state for Freerouting
2026-08-24 Restore un-routed FFC footprints for Freerouting
    [SplitChoc64_LEFT.kicad_pcb, SplitChoc64_RIGHT.kicad_pcb]
2026-08-24 Package current Ver001 FFC unrouted data
2026-08-26 Stage Ver001 finalized 3D payload part 00
2026-08-26 Stage Ver001 finalized 3D payload part 01
2026-08-26 Stage exact Ver001 3D payload 00
2026-08-26 Stage exact Ver001 3D payload 01
2026-08-26 Stage exact Ver001 3D payload 02
2026-08-26 Stage exact Ver001 3D payload 03
2026-08-26 Stage exact Ver001 3D payload 04
2026-08-26 Stage exact Ver001 3D payload 05
2026-08-26 TEMP inspect staged Ver001 3D payload
2026-08-31 Add separate Ver001 status LED and adjustable PWM backlight (#18)
    * Add Ver001 status LED and PWM backlight hardware
    * Enable adjustable PWM backlight on LEFT
    * Enable adjustable PWM backlight on RIGHT
    * Add Ver001 backlight toggle and brightness controls
    * Add Ver001 firmware-ready status LED
    * Compile Ver001 status LED support
    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
2026-09-02 Add one-shot workflow for reviewed XIAO pin-name fix
2026-09-02 Fix one-shot XIAO pin-name workflow syntax
2026-09-02 Use encoded one-shot XIAO pin-name fix script
2026-09-02 Fix XIAO nRF52840 Plus pin names
    [SplitChoc64_LEFT.kicad_sch, SplitChoc64_RIGHT.kicad_sch]
2026-09-02 Trigger CI for XIAO pin-name fix
2026-09-02 Stage Ver002 reviewed XIAO patch
2026-09-02 Promote reviewed SplitChoc64 hardware to Ver002
    [2N7002_SOT23_KICAD_ALIGNED.step, Hirose_FH19C-6S-0.5SH10_KICAD_ALIGNED.step, JST_S2B-PH-SM4-TB_KICAD_ALIGNED.step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]
